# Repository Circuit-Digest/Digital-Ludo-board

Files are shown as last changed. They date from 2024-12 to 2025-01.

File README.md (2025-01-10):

# [Digital-Ludo-board](https://circuitdigest.com/microcontroller-projects/build-a-smart-digital-game-board-using-multicolour-pcb)

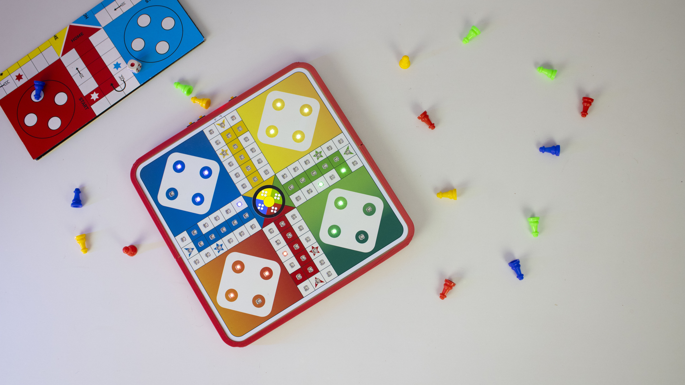
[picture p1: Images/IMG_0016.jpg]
Main Image


## Gallery

<table align="center">
  <tr>
    <td align="center">
      <a href="https://github.com/jobitjoseph/Digital-Ludo-board/blob/b7a14a51adeb144ec9624a0bab658bc6e6cb5062/Images/IMG_0016.jpg" target="_blank">
        
      </a>
    </td>
    <td align="center">
      <a href="https://github.com/jobitjoseph/Digital-Ludo-board/blob/fb9c06605a7f2c914b765a0e7e6bfde6a9d47ad6/Images/IMG_0014.jpg" target="_blank">
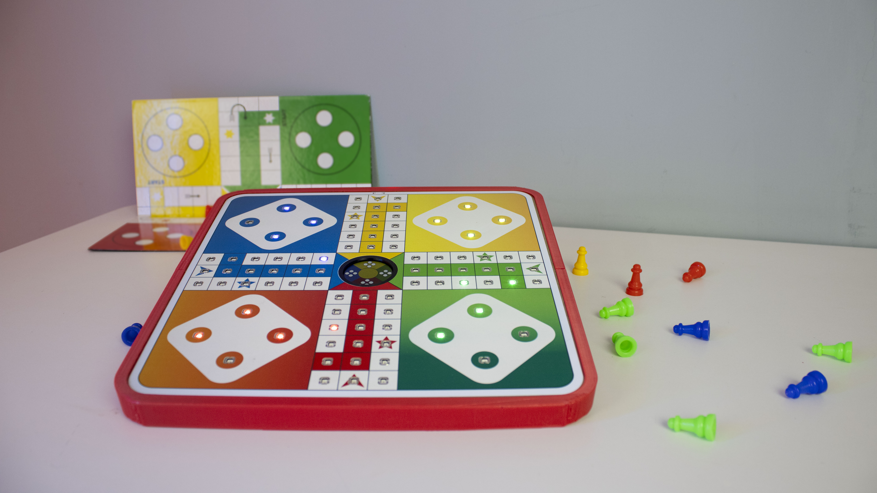
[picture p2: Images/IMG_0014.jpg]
        
      </a>
    </td>
  </tr>
  <tr>
    <td align="center">
      <a href="https://github.com/jobitjoseph/Digital-Ludo-board/blob/ef0574b0e37cc6b18bce47278ad40f484cababb1/Images/LudoRender1.png" target="_blank">
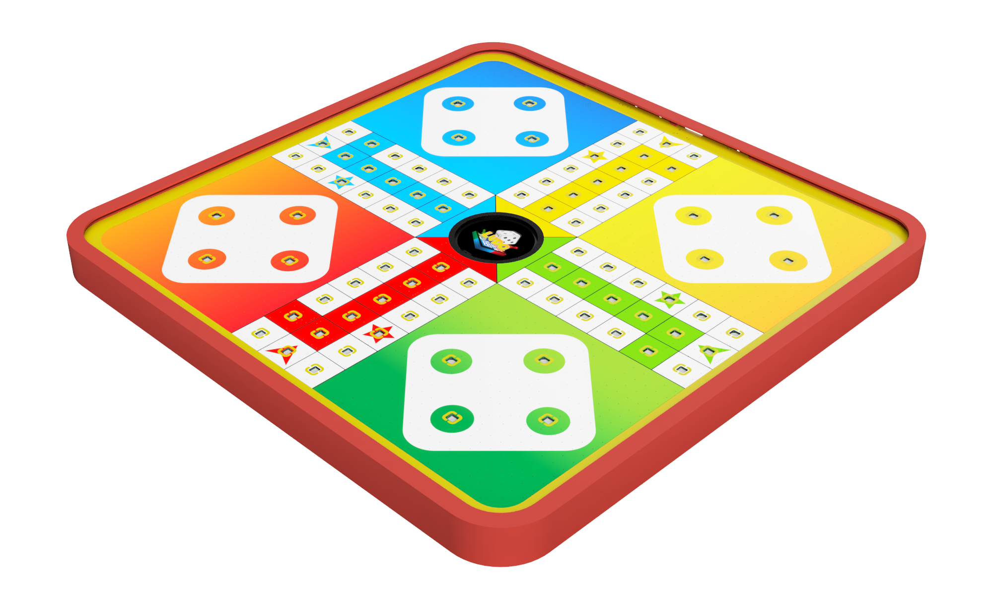
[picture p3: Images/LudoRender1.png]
        
      </a>
    </td>
    <td align="center">
      <a href="https://github.com/jobitjoseph/Digital-Ludo-board/blob/ef0574b0e37cc6b18bce47278ad40f484cababb1/Images/LudoRender2.png" target="_blank">
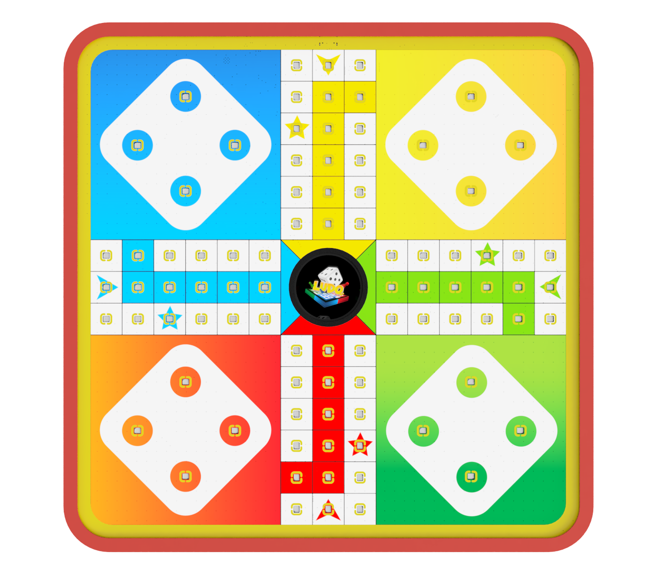
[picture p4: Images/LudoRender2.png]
        
      </a>
    </td>
  </tr>
</table>

---
Ludo, one of our cherished childhood board games, holds a special place in our hearts. Its simple yet engaging gameplay has provided countless hours of fun and bonding. However, as times have changed, so have our ways of enjoying these nostalgic pastimes. Today, children often experience classic games like Ludo through smartphones and gaming consoles, losing the physical gameplay and interpersonal connection of traditional board games.

What if we could bridge the gap between the old and the new by creating a digital version of the Ludo board? So let's create a Digital Ludo Board, a modern take on this classic game that combines the nostalgia of the physical game with the convenience and interactivity of the digital world. Designed and built from scratch, this is not only a fun project but also an opportunity to try out the new multicolor PCB.

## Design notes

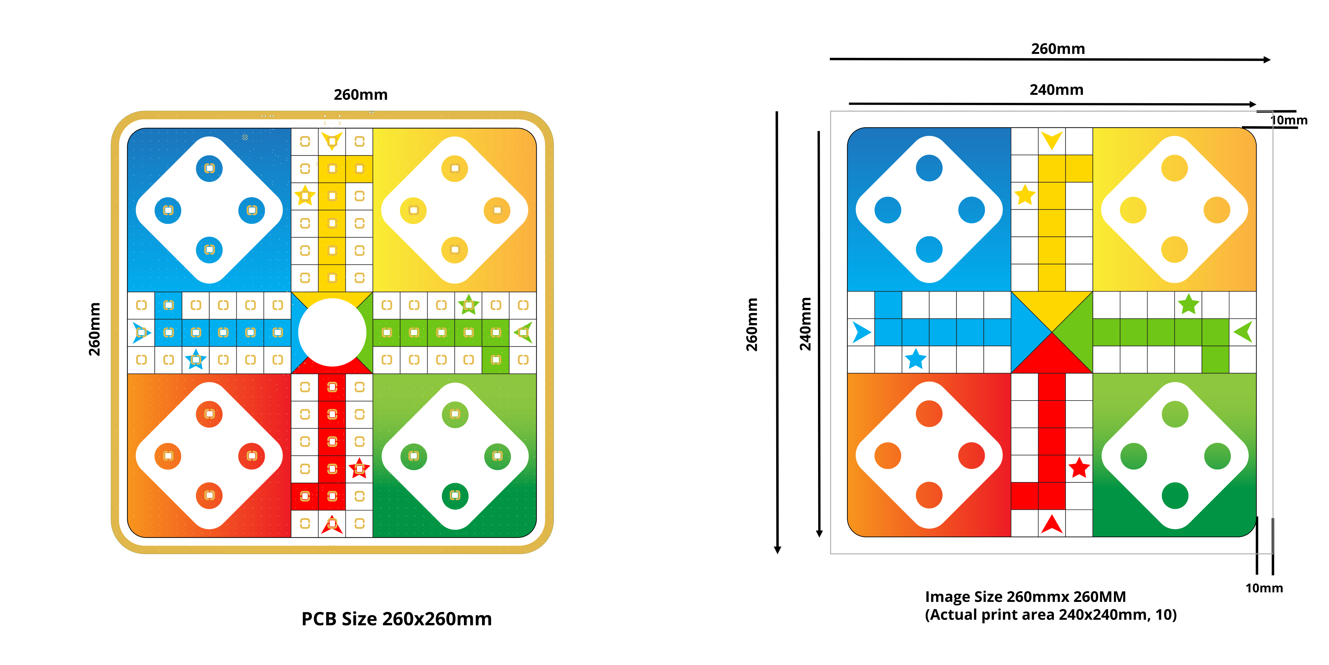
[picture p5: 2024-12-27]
Hardware/Reference image 1.png

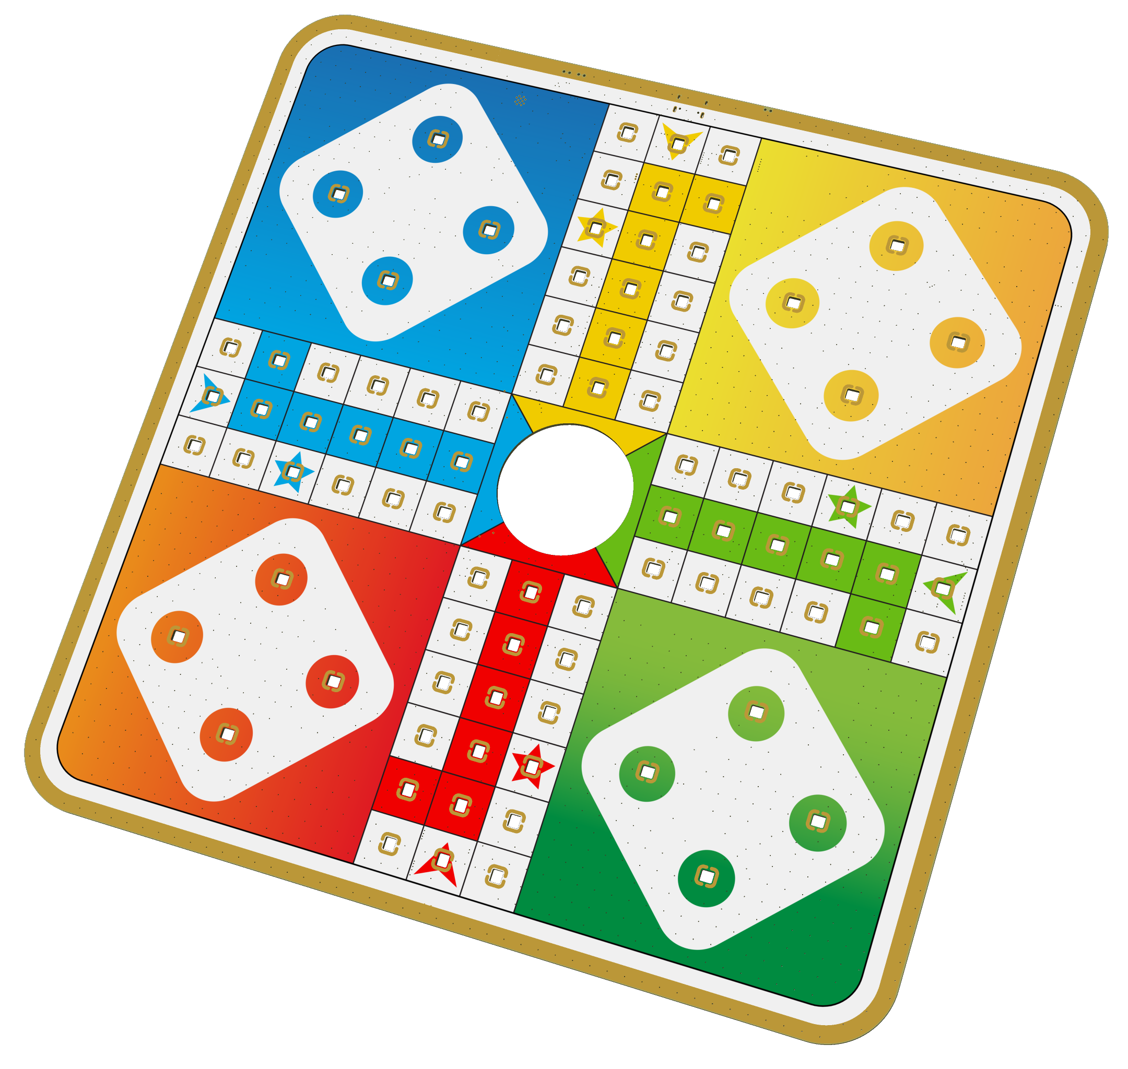
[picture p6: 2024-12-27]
Hardware/Reference image2.png

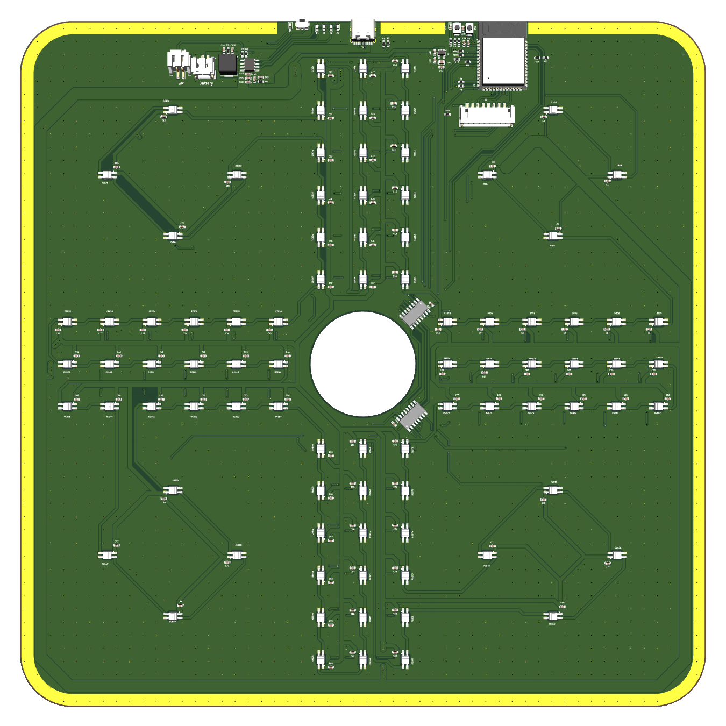
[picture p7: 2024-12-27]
Images/LudoBoard PCB 3D View Bottom.png

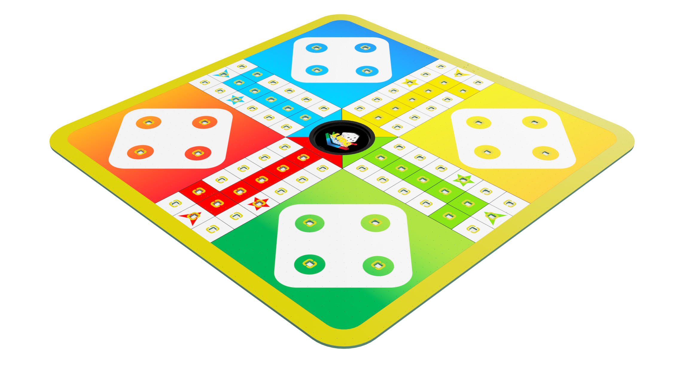
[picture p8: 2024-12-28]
Images/LUDO PCB 3D top.PNG

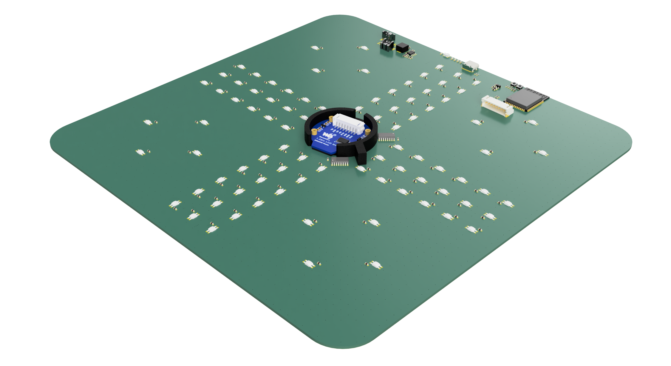
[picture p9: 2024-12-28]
Images/LUDO PCB 3D bottom.png

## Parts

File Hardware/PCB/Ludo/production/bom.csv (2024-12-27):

Designator | Footprint | Quantity | Value | LCSC Part #
C1, C10, C11, C12, C13, C14, C15, C16, C17, C18, C19, C2, C20, C21, C22, C23, C24, C25, C26, C27, C28, C29, C3, C30, C31, C32, C33, C34, C35, C36, C37, C38, C39, C4, C40, C41, C42, C43, C44, C45, C46, C47, C48, C49, C5, C50, C51, C52, C53, C54, C55, C56, C57, C58, C59, C6, C60, C61, C62, C63, C64, C65, C66, C67, C68, C69, C7, C70, C71, C72, C73, C74, C75, C76, C77, C78, C79, C8, C80, C81, C82, C83, C84, C85, C86, C87, C88, C9 | 0603 | 88 | 0.1uf
C100, C101, C103, C104 | 0603 | 4 | 22uf
C102 | 0603 | 1 | 22uf
C89, C92 | 0603 | 2 | 10u
C90 | 0603 | 1 | 470pF
C91 | 0805 | 1 | 2.2uF
C93, C96, C97, C98, C99 | 0603 | 5 | 10uf
C94 | 0603 | 1 | 1uf
C95 | 0603 | 1 | 0.1uf
D1 | 0603 | 1 | LED
D2, D3, D4, D5 | 0603 | 4 | LED
IC1, IC2 | 74HC595DQ100118 | 2 | 74HC595D
J1, J4 | JST_PH_S2B-PH-SM4-TB_1x02-1MP_P2.00mm_Horizontal | 2 | Conn_01x02_Male
J2 | USB_C_Receptacle_HRO_TYPE-C-31-M-12 | 1 | USB_C_Receptacle_USB2.0
J3 | JST_PH_S8B-PH-SM4-TB_1x08-1MP_P2.00mm_Horizontal | 1 | Conn_01x08
L1 | IND1uh | 1 | 1uH
LED2 | 0603 | 1 | POW_LED
R1, R2 | 0603 | 2 | 5.1K
R10 | 0603 | 1 | 20R
R11, R8 | 0603 | 2 | 2R
R12, R13, R14, R15, R16, R17, R18 | 0603 | 7 | 100k
R3, R4, R9 | 0603 | 3 | 10k
R5, R6 | 0603 | 2 | 27R
R7 | 0603 | 1 | 470R
RGB1, RGB10, RGB11, RGB12, RGB13, RGB14, RGB15, RGB16, RGB17, RGB18, RGB19, RGB2, RGB20, RGB21, RGB22, RGB23, RGB24, RGB25, RGB26, RGB27, RGB28, RGB29, RGB3, RGB30, RGB31, RGB32, RGB33, RGB34, RGB35, RGB36, RGB37, RGB38, RGB39, RGB4, RGB40, RGB41, RGB42, RGB43, RGB44, RGB45, RGB46, RGB47, RGB48, RGB49, RGB5, RGB50, RGB51, RGB52, RGB53, RGB54, RGB55, RGB56, RGB57, RGB58, RGB59, RGB6, RGB60, RGB61, RGB62, RGB63, RGB64, RGB65, RGB66, RGB67, RGB68, RGB69, RGB7, RGB70, RGB71, RGB72, RGB73, RGB74, RGB75, RGB76, RGB77, RGB78, RGB79, RGB8, RGB80, RGB81, RGB82, RGB83, RGB84, RGB85, RGB86, RGB87, RGB88, RGB9 | SK6812MINI-E_1 | 88 | SK6812MINI-E_C5149201
SW1 | Tactile 3x4x2mm TS-A010 | 1 | Boot
SW2 | Tactile 3x4x2mm TS-A010 | 1 | RST
SW3 | SW-SMD_TS24CA | 1 | Boot
U1 | IP5306-SOP8 | 1 | IP5306
U3 | ESP32-S3-WROOM-1 | 1 | ESP32-S3-WROOM-1
U6 | SOT-23-5 | 1 | MIC5219-3.3YM5

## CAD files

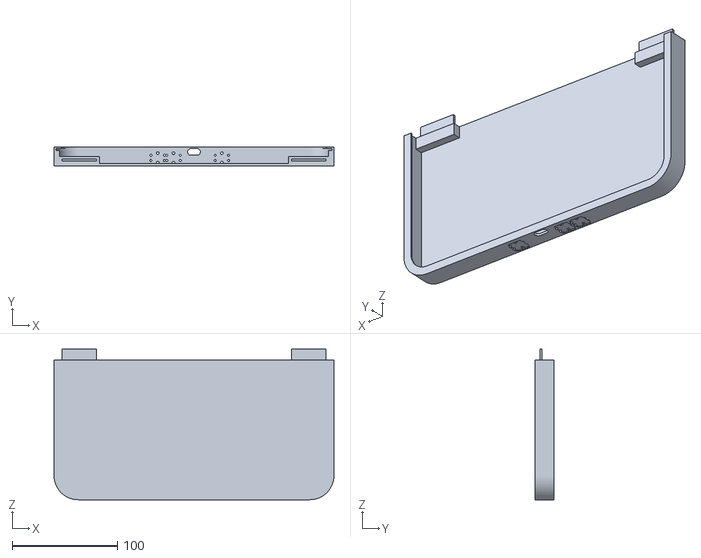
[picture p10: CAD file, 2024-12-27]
Hardware/3D parts/EnclosurePart2.stl
266.0 x 17.6 x 143.0

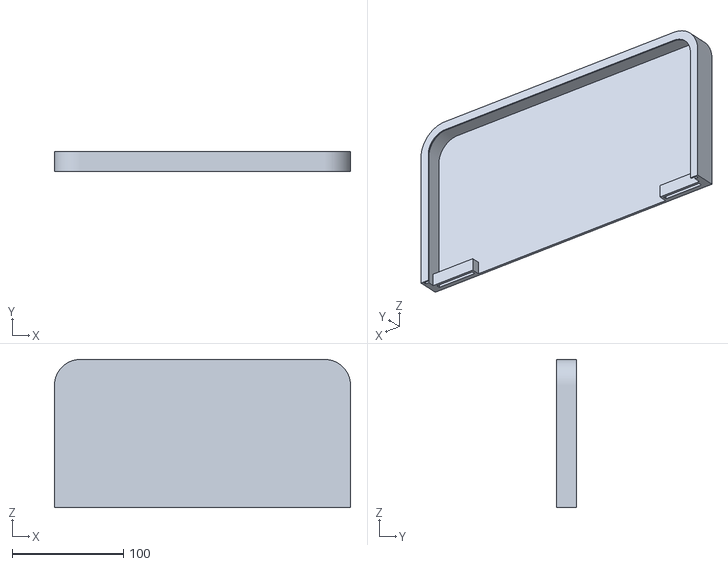
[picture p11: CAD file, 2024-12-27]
Hardware/3D parts/EnclosurePart1.stl
266.0 x 17.6 x 133.0

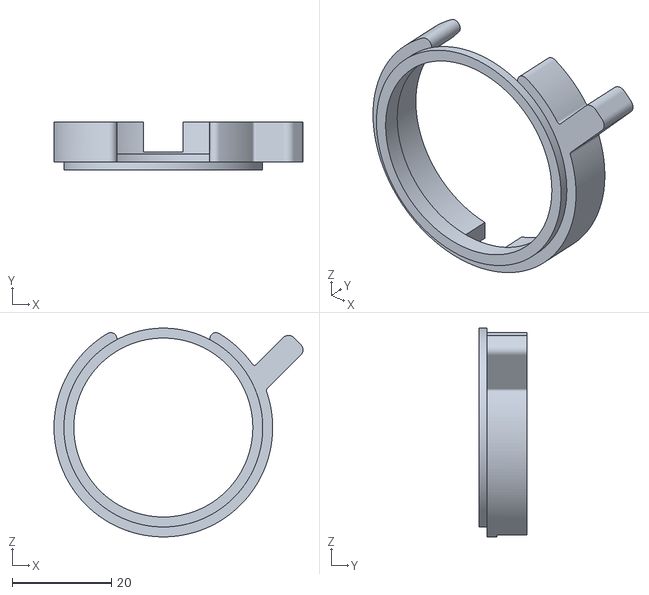
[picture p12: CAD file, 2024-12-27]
Hardware/3D parts/LCDMount.stl
50.1 x 9.60 x 42.0

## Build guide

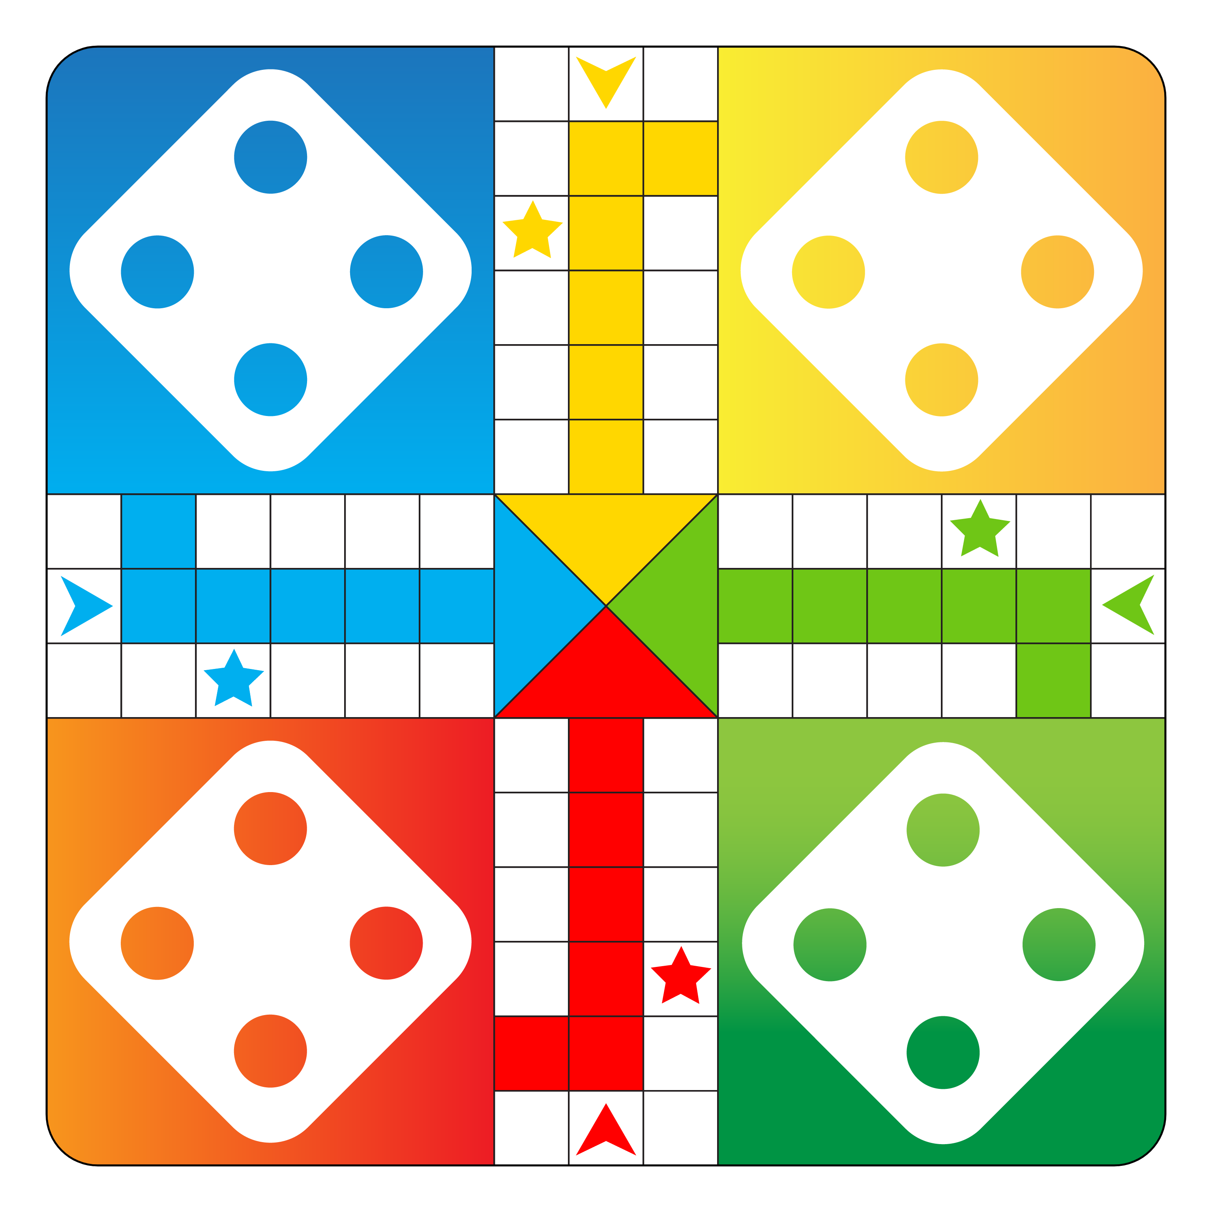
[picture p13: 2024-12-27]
Hardware/Top UV Printing Image .png

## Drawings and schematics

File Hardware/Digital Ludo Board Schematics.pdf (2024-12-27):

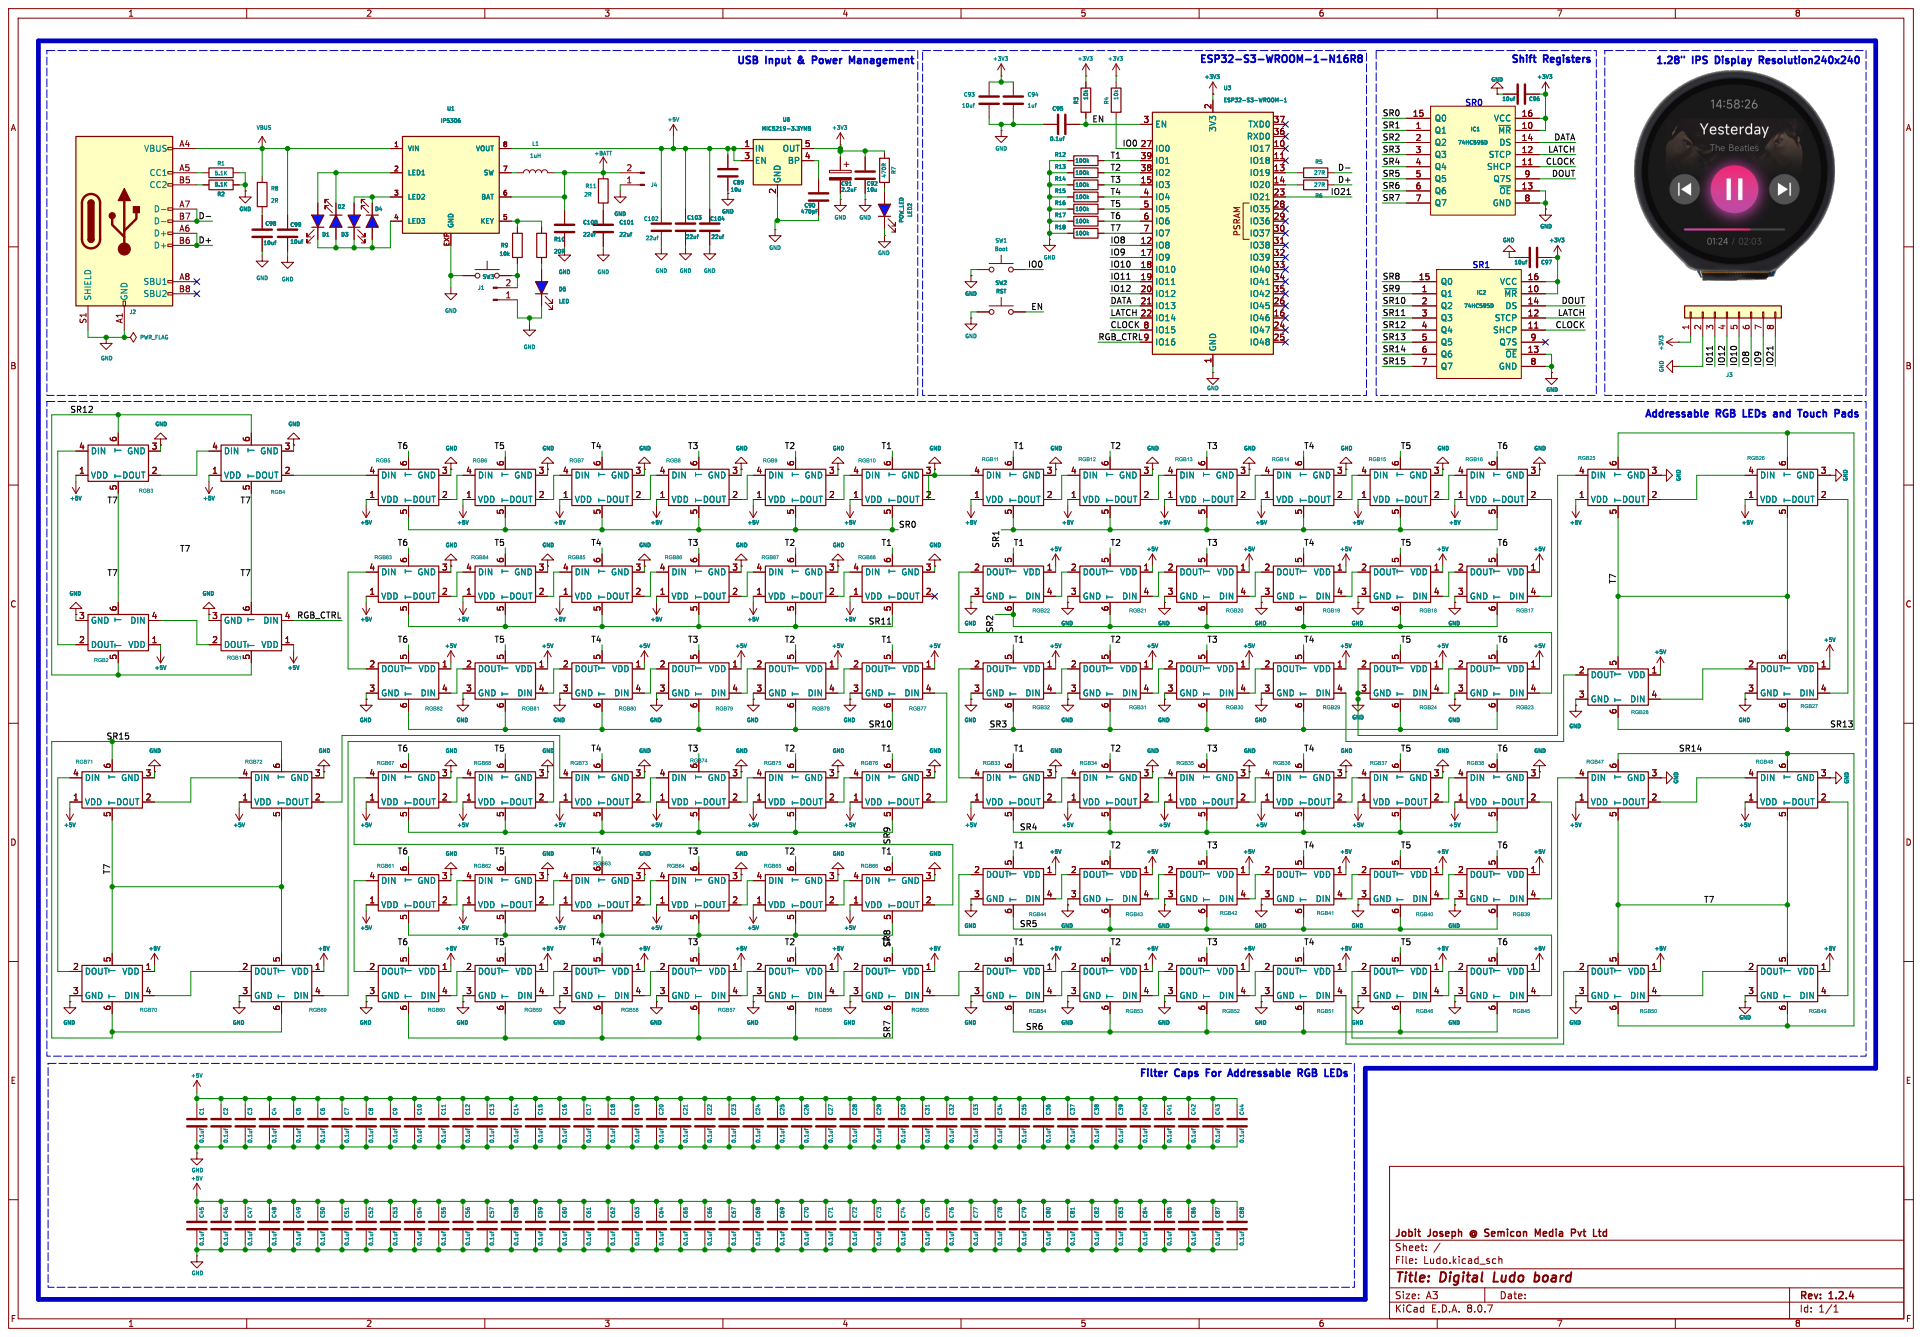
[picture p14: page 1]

Filter Caps For Addressable RGB LEDs

Id: 1/1 Title: Digital Ludo board

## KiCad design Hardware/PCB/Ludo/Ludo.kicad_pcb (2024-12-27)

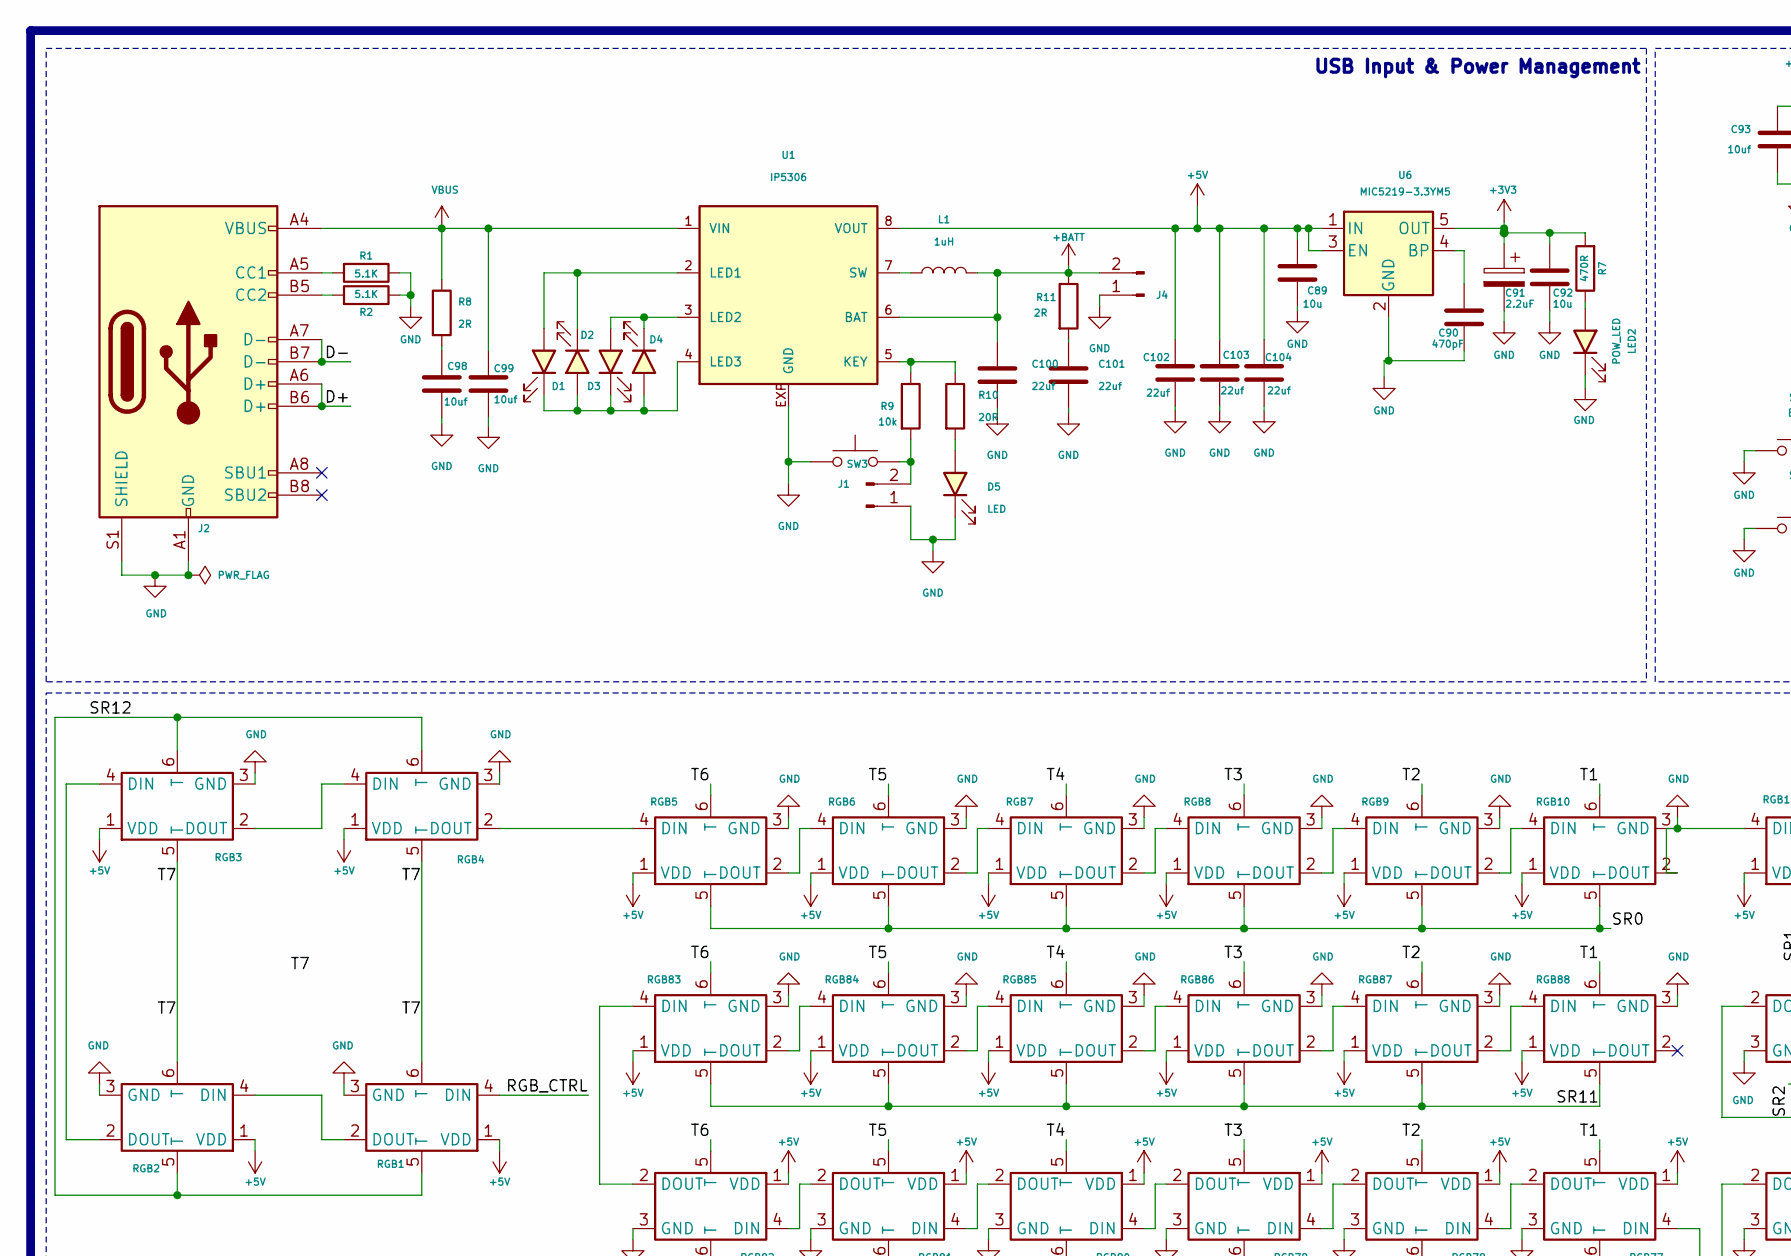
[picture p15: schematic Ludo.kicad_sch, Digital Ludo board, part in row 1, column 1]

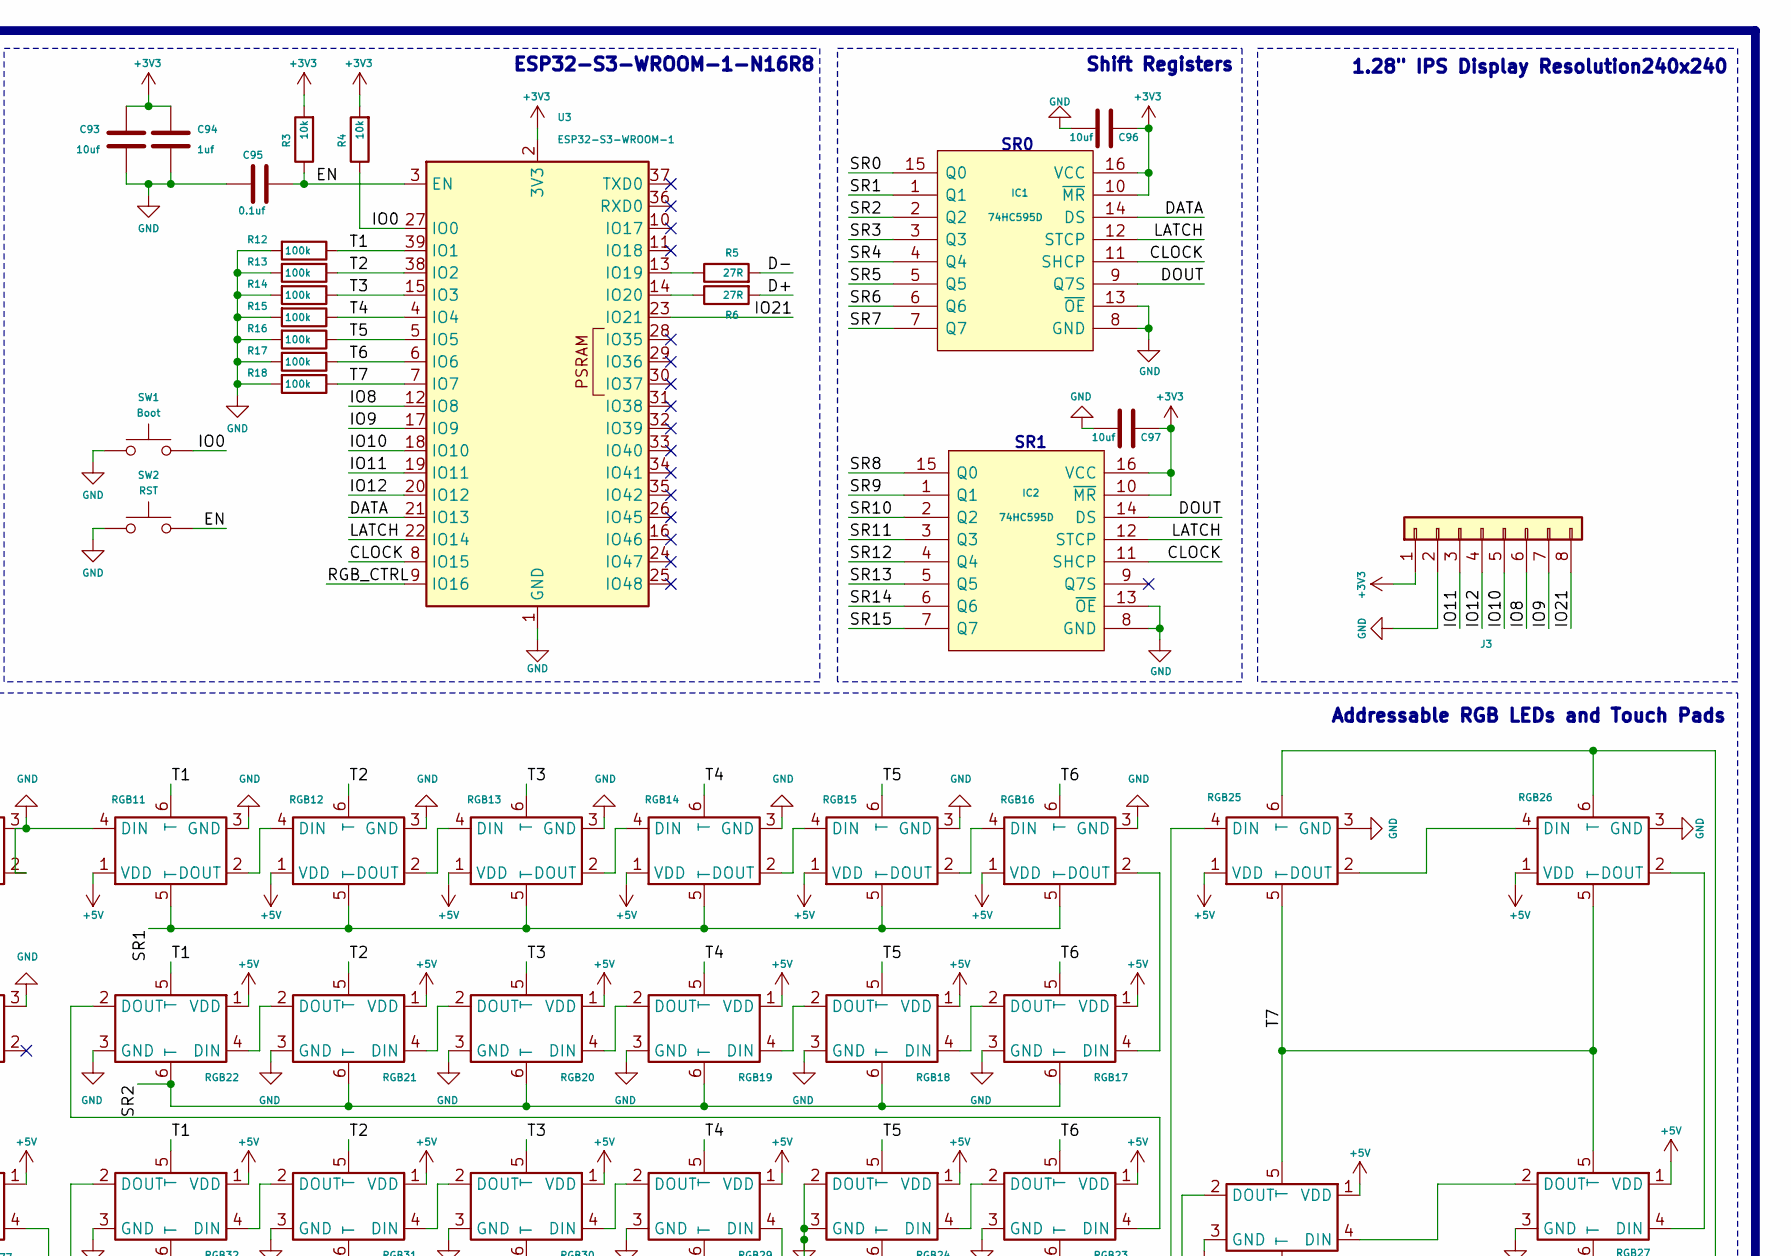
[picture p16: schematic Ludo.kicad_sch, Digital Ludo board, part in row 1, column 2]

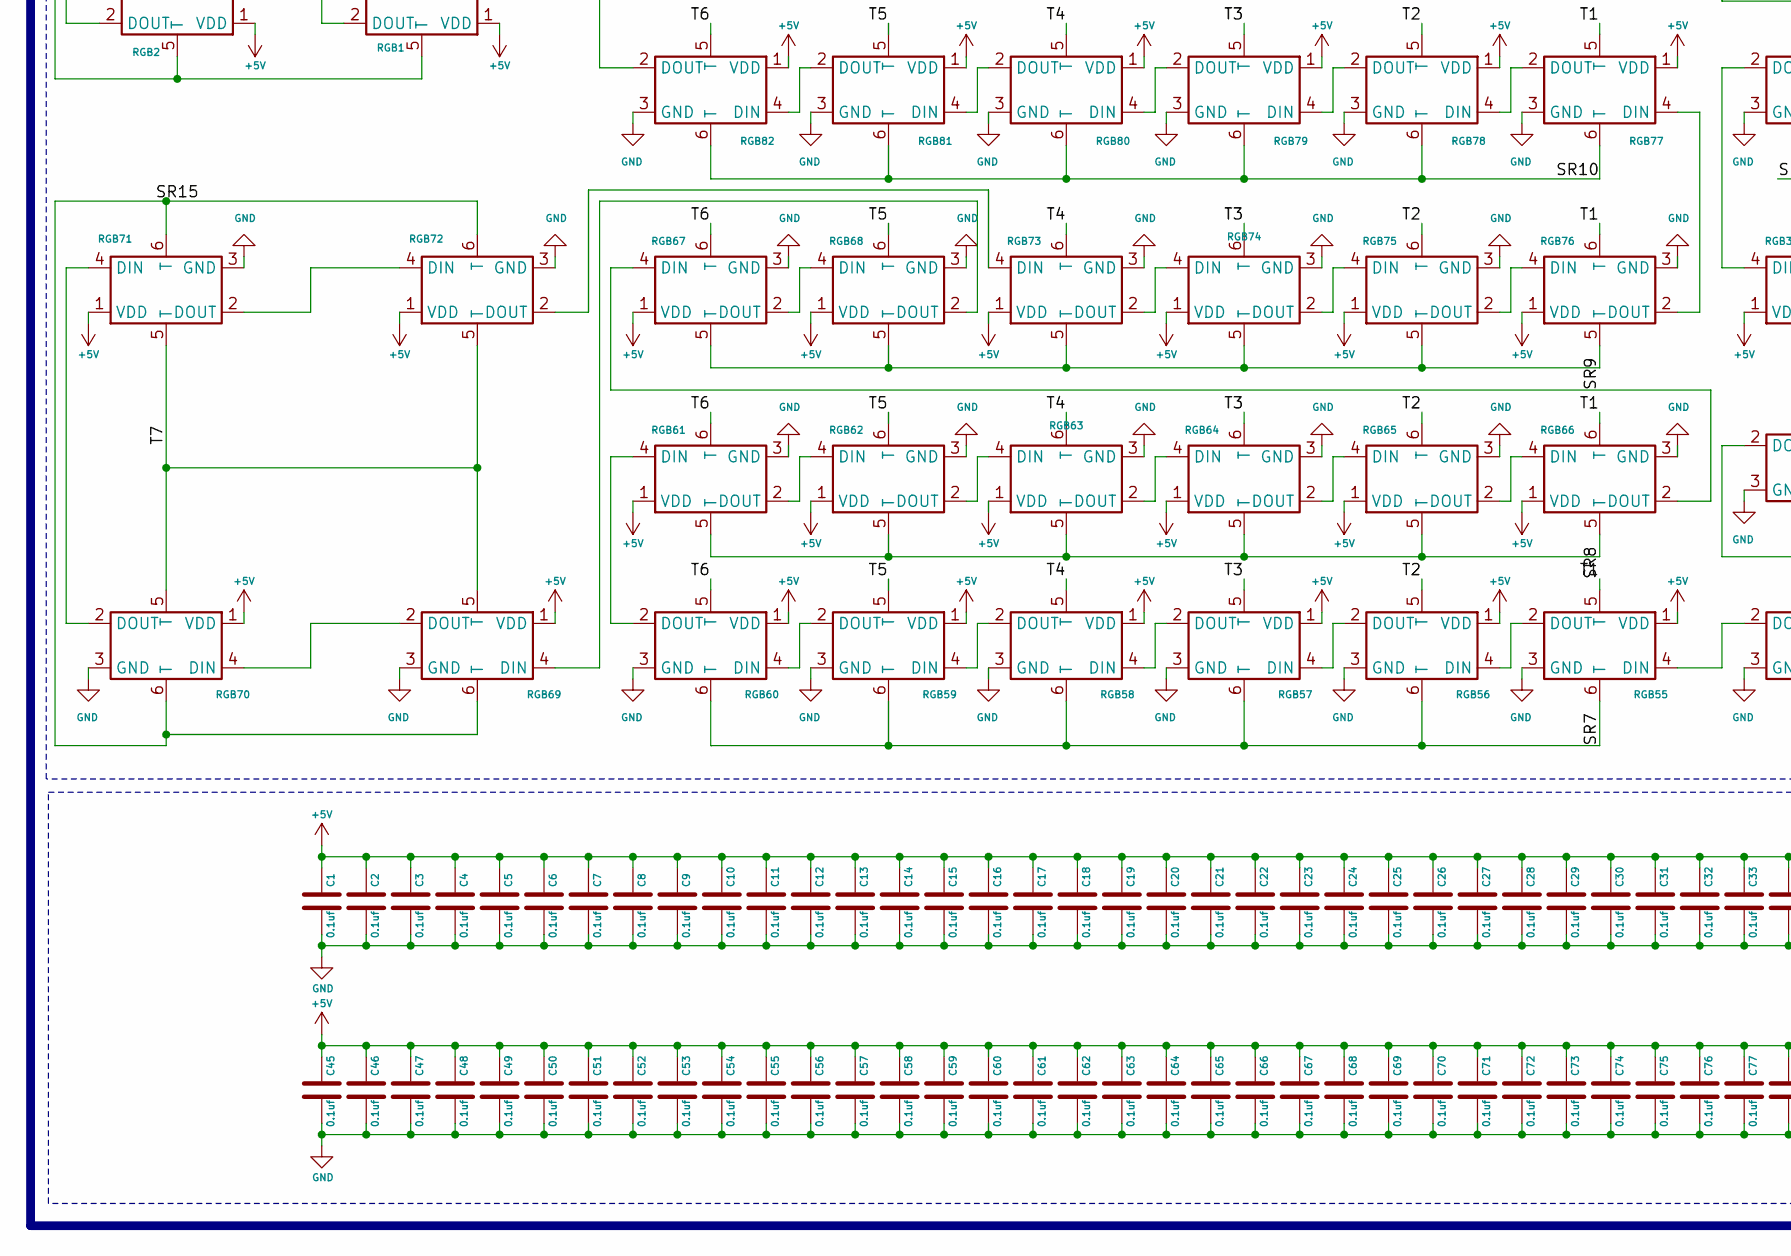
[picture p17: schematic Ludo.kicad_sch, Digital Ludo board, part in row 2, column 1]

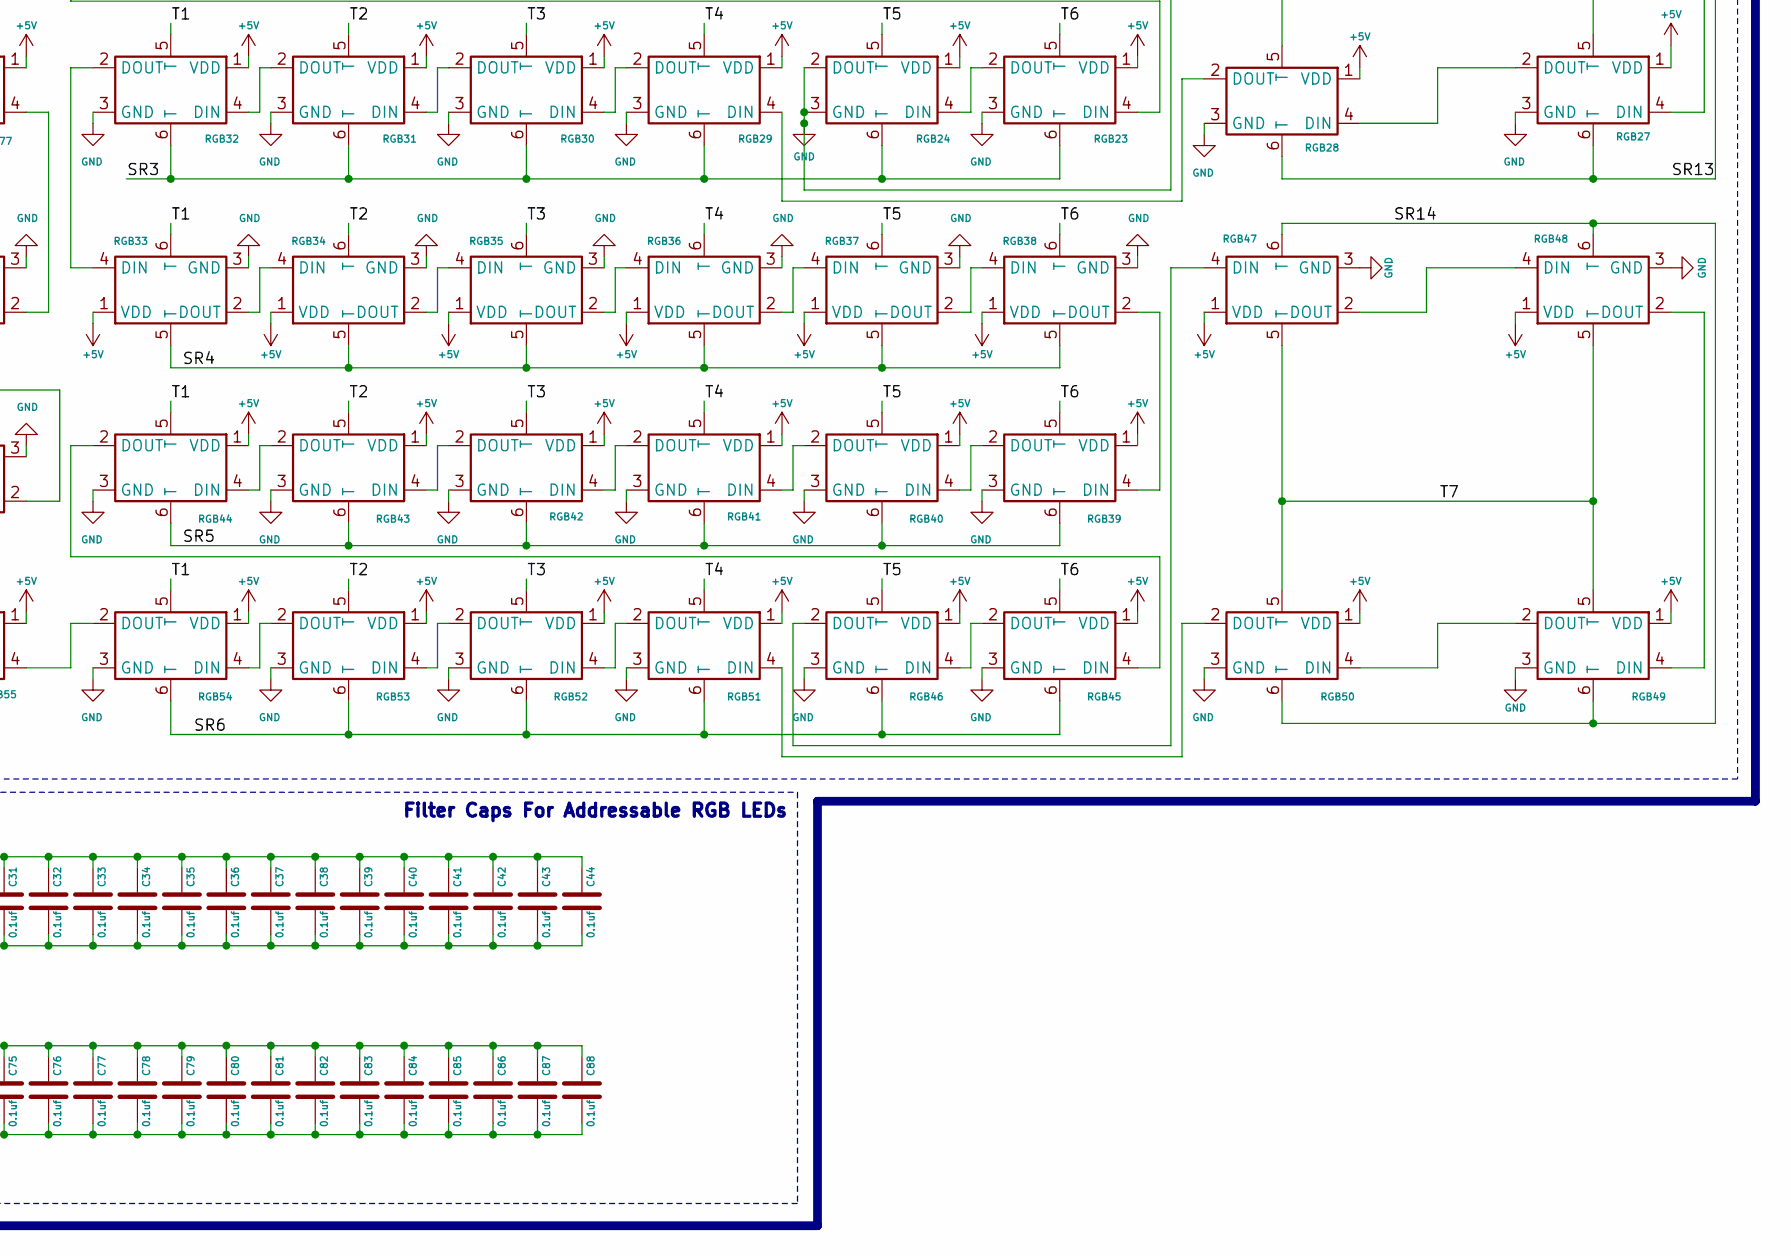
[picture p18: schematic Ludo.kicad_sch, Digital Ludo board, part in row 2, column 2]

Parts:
C1, C2, C3, C4, C5, C6, C7, C8, C9, C10, C11, C12, C13, C14, C15, C16, C17, C18, C19, C20, C21, C22, C23, C24, C25, C26, C27, C28, C29, C30, C31, C32, C33, C34, C35, C36, C37, C38, C39, C40, C41, C42, C43, C44, C45, C46, C47, C48, C49, C50, C51, C52, C53, C54, C55, C56, C57, C58, C59, C60, C61, C62, C63, C64, C65, C66, C67, C68, C69, C70, C71, C72, C73, C74, C75, C76, C77, C78, C79, C80, C81, C82, C83, C84, C85, C86, C87, C88, C95: 0.1uf; C_0603_1608Metric
C89, C92: 10u; C_0603_1608Metric
C90: 470pF; C_0603_1608Metric
C91: 2.2uF; C_0805_2012Metric
C93, C96, C97, C98, C99: 10uf; C_0603_1608Metric
C94: 1uf; C_0603_1608Metric
C100, C101, C102, C103, C104: 22uf; C_0603_1608Metric
D1, D2, D3, D4, D5: LED; LED_0603_1608Metric
IC1, IC2: 74HC595D; 74HC595DQ100118; Mouser Part Number 771-74HC595D-Q100
J1, J4: Conn_01x02_Male; JST_PH_S2B-PH-SM4-TB_1x02-1MP_P2.00mm_Horizontal
J2: USB_C_Receptacle_USB2.0; USB_C_Receptacle_HRO_TYPE-C-31-M-12
J3: Conn_01x08; JST_PH_S8B-PH-SM4-TB_1x08-1MP_P2.00mm_Horizontal
L1: 1uH; IND1uh
LED2: POW_LED; LED_0603_1608Metric
R1, R2: 5.1K; R_0603_1608Metric
R3, R4, R9: 10k; R_0603_1608Metric
R5, R6: 27R; R_0603_1608Metric
R7: 470R; R_0603_1608Metric
R8, R11: 2R; R_0603_1608Metric
R10: 20R; R_0603_1608Metric
R12, R13, R14, R15, R16, R17, R18: 100k; R_0603_1608Metric
RGB1, RGB2, RGB3, RGB4, RGB5, RGB6, RGB7, RGB8, RGB9, RGB10, RGB11, RGB12, RGB13, RGB14, RGB15, RGB16, RGB17, RGB18, RGB19, RGB20, RGB21, RGB22, RGB23, RGB24, RGB25, RGB26, RGB27, RGB28, RGB29, RGB30, RGB31, RGB32, RGB33, RGB34, RGB35, RGB36, RGB37, RGB38, RGB39, RGB40, RGB41, RGB42, RGB43, RGB44, RGB45, RGB46, RGB47, RGB48, RGB49, RGB50, RGB51, RGB52, RGB53, RGB54, RGB55, RGB56, RGB57, RGB58, RGB59, RGB60, RGB61, RGB62, RGB63, RGB64, RGB65, RGB66, RGB67, RGB68, RGB69, RGB70, RGB71, RGB72, RGB73, RGB74, RGB75, RGB76, RGB77, RGB78, RGB79, RGB80, RGB81, RGB82, RGB83, RGB84, RGB85, RGB86, RGB87, RGB88: SK6812MINI-E_C5149201; SK6812MINI-E_1
SW1: Boot; Tactile 3x4x2mm TS-A010
SW2: RST; Tactile 3x4x2mm TS-A010
SW3: Boot; SW-SMD_TS24CA
U1: IP5306; IP5306-SOP8
U3: ESP32-S3-WROOM-1
U6: MIC5219-3.3YM5; SOT-23-5

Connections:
+3V3: C91.1, C92.1, C93.1, C94.1, C96.1, C97.1, IC1.10 (~MR), IC1.16 (VCC), IC2.10 (~MR), IC2.16 (VCC), J3.1, R3.2, R4.2, R7.2, U3.2 (3V3), U6.5 (OUT)
+5V: C1.1, C2.1, C3.1, C4.1, C5.1, C6.1, C7.1, C8.1, C9.1, C10.1, C11.1, C12.1, C13.1, C14.1, C15.1, C16.1, C17.1, C18.1, C19.1, C20.1, C21.1, C22.1, C23.1, C24.1, C25.1, C26.1, C27.1, C28.1, C29.1, C30.1, C31.1, C32.1, C33.1, C34.1, C35.1, C36.1, C37.1, C38.1, C39.1, C40.1, C41.1, C42.1, C43.1, C44.1, C45.1, C46.1, C47.1, C48.1, C49.1, C50.1, C51.1, C52.1, C53.1, C54.1, C55.1, C56.1, C57.1, C58.1, C59.1, C60.1, C61.1, C62.1, C63.1, C64.1, C65.1, C66.1, C67.1, C68.1, C69.1, C70.1, C71.1, C72.1, C73.1, C74.1, C75.1, C76.1, C77.1, C78.1, C79.1, C80.1, C81.1, C82.1, C83.1, C84.1, C85.1, C86.1, C87.1, C88.1, C89.1, C102.1, C103.1, C104.1, RGB1.1 (VDD), RGB2.1 (VDD), RGB3.1 (VDD), RGB4.1 (VDD), RGB5.1 (VDD), RGB6.1 (VDD), RGB7.1 (VDD), RGB8.1 (VDD), RGB9.1 (VDD), RGB10.1 (VDD), RGB11.1 (VDD), RGB12.1 (VDD), RGB13.1 (VDD), RGB14.1 (VDD), RGB15.1 (VDD), RGB16.1 (VDD), RGB17.1 (VDD), RGB18.1 (VDD), RGB19.1 (VDD), RGB20.1 (VDD), RGB21.1 (VDD), RGB22.1 (VDD), RGB23.1 (VDD), RGB24.1 (VDD), RGB25.1 (VDD), RGB26.1 (VDD), RGB27.1 (VDD), RGB28.1 (VDD), RGB29.1 (VDD), RGB30.1 (VDD), RGB31.1 (VDD), RGB32.1 (VDD), RGB33.1 (VDD), RGB34.1 (VDD), RGB35.1 (VDD), RGB36.1 (VDD), RGB37.1 (VDD), RGB38.1 (VDD), RGB39.1 (VDD), RGB40.1 (VDD), RGB41.1 (VDD), RGB42.1 (VDD), RGB43.1 (VDD), RGB44.1 (VDD), RGB45.1 (VDD), RGB46.1 (VDD), RGB47.1 (VDD), RGB48.1 (VDD), RGB49.1 (VDD), RGB50.1 (VDD), RGB51.1 (VDD), RGB52.1 (VDD), RGB53.1 (VDD), RGB54.1 (VDD), RGB55.1 (VDD), RGB56.1 (VDD), RGB57.1 (VDD), RGB58.1 (VDD), RGB59.1 (VDD), RGB60.1 (VDD), RGB61.1 (VDD), RGB62.1 (VDD), RGB63.1 (VDD), RGB64.1 (VDD), RGB65.1 (VDD), RGB66.1 (VDD), RGB67.1 (VDD), RGB68.1 (VDD), RGB69.1 (VDD), RGB70.1 (VDD), RGB71.1 (VDD), RGB72.1 (VDD), RGB73.1 (VDD), RGB74.1 (VDD), RGB75.1 (VDD), RGB76.1 (VDD), RGB77.1 (VDD), RGB78.1 (VDD), RGB79.1 (VDD), RGB80.1 (VDD), RGB81.1 (VDD), RGB82.1 (VDD), RGB83.1 (VDD), RGB84.1 (VDD), RGB85.1 (VDD), RGB86.1 (VDD), RGB87.1 (VDD), RGB88.1 (VDD), U1.8 (VOUT), U6.1 (IN), U6.3 (EN)
+BATT: C100.1, J4.2, L1.2, R11.1, U1.6 (BAT)
/CLOCK: IC1.11 (SHCP), IC2.11 (SHCP), U3.8 (IO15)
/D+: J2.A6 (D+), J2.B6 (D+), R6.2
/D-: J2.A7 (D-), J2.B7 (D-), R5.2
/DATA: IC1.14 (DS), U3.21 (IO13)
/DOUT: IC1.9 (Q7S), IC2.14 (DS)
/EN: C95.1, R3.1, SW2.2, U3.3 (EN)
/IO0: R4.1, SW1.2, U3.27 (IO0)
/IO8: J3.6, U3.12 (IO8)
/IO9: J3.7, U3.17 (IO9)
/IO10: J3.5, U3.18 (IO10)
/IO11: J3.3, U3.19 (IO11)
/IO12: J3.4, U3.20 (IO12)
/IO21: J3.8, U3.23 (IO21)
/LATCH: IC1.12 (STCP), IC2.12 (STCP), U3.22 (IO14)
/RGB_CTRL: RGB1.4 (DIN), U3.9 (IO16)
/SR0: IC1.15 (Q0), RGB5.5 (T), RGB6.5 (T), RGB7.5 (T), RGB8.5 (T), RGB9.5 (T), RGB10.5 (T)
/SR1: IC1.1 (Q1), RGB11.5 (T), RGB12.5 (T), RGB13.5 (T), RGB14.5 (T), RGB15.5 (T), RGB16.5 (T)
/SR2: IC1.2 (Q2), RGB17.6 (T), RGB18.6 (T), RGB19.6 (T), RGB20.6 (T), RGB21.6 (T), RGB22.6 (T)
/SR3: IC1.3 (Q3), RGB23.6 (T), RGB24.6 (T), RGB29.6 (T), RGB30.6 (T), RGB31.6 (T), RGB32.6 (T)
/SR4: IC1.4 (Q4), RGB33.5 (T), RGB34.5 (T), RGB35.5 (T), RGB36.5 (T), RGB37.5 (T), RGB38.5 (T)
/SR5: IC1.5 (Q5), RGB39.6 (T), RGB40.6 (T), RGB41.6 (T), RGB42.6 (T), RGB43.6 (T), RGB44.6 (T)
/SR6: IC1.6 (Q6), RGB45.6 (T), RGB46.6 (T), RGB51.6 (T), RGB52.6 (T), RGB53.6 (T), RGB54.6 (T)
/SR7: IC1.7 (Q7), RGB55.6 (T), RGB56.6 (T), RGB57.6 (T), RGB58.6 (T), RGB59.6 (T), RGB60.6 (T)
/SR8: IC2.15 (Q0), RGB61.5 (T), RGB62.5 (T), RGB63.5 (T), RGB64.5 (T), RGB65.5 (T), RGB66.5 (T)
/SR9: IC2.1 (Q1), RGB67.5 (T), RGB68.5 (T), RGB73.5 (T), RGB74.5 (T), RGB75.5 (T), RGB76.5 (T)
/SR10: IC2.2 (Q2), RGB77.6 (T), RGB78.6 (T), RGB79.6 (T), RGB80.6 (T), RGB81.6 (T), RGB82.6 (T)
/SR11: IC2.3 (Q3), RGB83.5 (T), RGB84.5 (T), RGB85.5 (T), RGB86.5 (T), RGB87.5 (T), RGB88.5 (T)
/SR12: IC2.4 (Q4), RGB1.5 (T), RGB2.5 (T), RGB3.6 (T), RGB4.6 (T)
/SR13: IC2.5 (Q5), RGB25.6 (T), RGB26.6 (T), RGB27.6 (T), RGB28.6 (T)
/SR14: IC2.6 (Q6), RGB47.6 (T), RGB48.6 (T), RGB49.6 (T), RGB50.6 (T)
/SR15: IC2.7 (Q7), RGB69.6 (T), RGB70.6 (T), RGB71.6 (T), RGB72.6 (T)
/T1: R12.1, RGB10.6 (T), RGB11.6 (T), RGB22.5 (T), RGB32.5 (T), RGB33.6 (T), RGB44.5 (T), RGB54.5 (T), RGB55.5 (T), RGB66.6 (T), RGB76.6 (T), RGB77.5 (T), RGB88.6 (T), U3.39 (IO1)
/T2: R13.1, RGB9.6 (T), RGB12.6 (T), RGB21.5 (T), RGB31.5 (T), RGB34.6 (T), RGB43.5 (T), RGB53.5 (T), RGB56.5 (T), RGB65.6 (T), RGB75.6 (T), RGB78.5 (T), RGB87.6 (T), U3.38 (IO2)
/T3: R14.1, RGB8.6 (T), RGB13.6 (T), RGB20.5 (T), RGB30.5 (T), RGB35.6 (T), RGB42.5 (T), RGB52.5 (T), RGB57.5 (T), RGB64.6 (T), RGB74.6 (T), RGB79.5 (T), RGB86.6 (T), U3.15 (IO3)
/T4: R15.1, RGB7.6 (T), RGB14.6 (T), RGB19.5 (T), RGB29.5 (T), RGB36.6 (T), RGB41.5 (T), RGB51.5 (T), RGB58.5 (T), RGB63.6 (T), RGB73.6 (T), RGB80.5 (T), RGB85.6 (T), U3.4 (IO4)
/T5: R16.1, RGB6.6 (T), RGB15.6 (T), RGB18.5 (T), RGB24.5 (T), RGB37.6 (T), RGB40.5 (T), RGB46.5 (T), RGB59.5 (T), RGB62.6 (T), RGB68.6 (T), RGB81.5 (T), RGB84.6 (T), U3.5 (IO5)
/T6: R17.1, RGB5.6 (T), RGB16.6 (T), RGB17.5 (T), RGB23.5 (T), RGB38.6 (T), RGB39.5 (T), RGB45.5 (T), RGB60.5 (T), RGB61.6 (T), RGB67.6 (T), RGB82.5 (T), RGB83.6 (T), U3.6 (IO6)
/T7: R18.1, RGB1.6 (T), RGB2.6 (T), RGB3.5 (T), RGB4.5 (T), RGB25.5 (T), RGB26.5 (T), RGB27.5 (T), RGB28.5 (T), RGB47.5 (T), RGB48.5 (T), RGB49.5 (T), RGB50.5 (T), RGB69.5 (T), RGB70.5 (T), RGB71.5 (T), RGB72.5 (T), U3.7 (IO7)
unnamed: C98.1, R8.2
unnamed: C101.1, R11.2
unnamed: D1.2 (A), D2.1 (K), U1.2 (LED1)
unnamed: D1.1 (K), D2.2 (A), D3.1 (K), D4.2 (A), U1.4 (LED3)
unnamed: D3.2 (A), D4.1 (K), U1.3 (LED2)
unnamed: D5.2 (A), R10.2
unnamed: J1.2, R9.2, SW3.2
unnamed: J2.A5 (CC1), R1.2
unnamed: J2.B5 (CC2), R2.2
unnamed: LED2.2 (A), R7.1
unnamed: RGB1.2 (DOUT), RGB2.4 (DIN)
unnamed: RGB2.2 (DOUT), RGB3.4 (DIN)
unnamed: RGB3.2 (DOUT), RGB4.4 (DIN)
unnamed: RGB4.2 (DOUT), RGB5.4 (DIN)
unnamed: RGB5.2 (DOUT), RGB6.4 (DIN)
unnamed: RGB6.2 (DOUT), RGB7.4 (DIN)
unnamed: RGB7.2 (DOUT), RGB8.4 (DIN)
unnamed: RGB8.2 (DOUT), RGB9.4 (DIN)
unnamed: RGB9.2 (DOUT), RGB10.4 (DIN)
unnamed: RGB11.2 (DOUT), RGB12.4 (DIN)
unnamed: RGB12.2 (DOUT), RGB13.4 (DIN)
unnamed: RGB13.2 (DOUT), RGB14.4 (DIN)
unnamed: RGB14.2 (DOUT), RGB15.4 (DIN)
unnamed: RGB15.2 (DOUT), RGB16.4 (DIN)
unnamed: RGB16.2 (DOUT), RGB17.4 (DIN)
unnamed: RGB17.2 (DOUT), RGB18.4 (DIN)
unnamed: RGB18.2 (DOUT), RGB19.4 (DIN)
unnamed: RGB19.2 (DOUT), RGB20.4 (DIN)
unnamed: RGB20.2 (DOUT), RGB21.4 (DIN)
unnamed: RGB21.2 (DOUT), RGB22.4 (DIN)
unnamed: RGB22.2 (DOUT), RGB23.4 (DIN)
unnamed: RGB23.2 (DOUT), RGB24.4 (DIN)
unnamed: RGB25.2 (DOUT), RGB26.4 (DIN)
unnamed: RGB26.2 (DOUT), RGB27.4 (DIN)
unnamed: RGB27.2 (DOUT), RGB28.4 (DIN)
unnamed: RGB28.2 (DOUT), RGB29.4 (DIN)
unnamed: RGB29.2 (DOUT), RGB30.4 (DIN)
unnamed: RGB30.2 (DOUT), RGB31.4 (DIN)
unnamed: RGB31.2 (DOUT), RGB32.4 (DIN)
unnamed: RGB32.2 (DOUT), RGB33.4 (DIN)
unnamed: RGB33.2 (DOUT), RGB34.4 (DIN)
unnamed: RGB34.2 (DOUT), RGB35.4 (DIN)
unnamed: RGB35.2 (DOUT), RGB36.4 (DIN)
unnamed: RGB36.2 (DOUT), RGB37.4 (DIN)
unnamed: RGB37.2 (DOUT), RGB38.4 (DIN)
unnamed: RGB38.2 (DOUT), RGB39.4 (DIN)
unnamed: RGB39.2 (DOUT), RGB40.4 (DIN)
unnamed: RGB40.2 (DOUT), RGB41.4 (DIN)
unnamed: RGB41.2 (DOUT), RGB42.4 (DIN)
unnamed: RGB42.2 (DOUT), RGB43.4 (DIN)
unnamed: RGB43.2 (DOUT), RGB44.4 (DIN)
unnamed: RGB44.2 (DOUT), RGB45.4 (DIN)
unnamed: RGB45.2 (DOUT), RGB46.4 (DIN)
unnamed: RGB46.2 (DOUT), RGB47.4 (DIN)
unnamed: RGB47.2 (DOUT), RGB48.4 (DIN)
unnamed: RGB48.2 (DOUT), RGB49.4 (DIN)
unnamed: RGB49.2 (DOUT), RGB50.4 (DIN)
unnamed: RGB50.2 (DOUT), RGB51.4 (DIN)
unnamed: RGB51.2 (DOUT), RGB52.4 (DIN)
unnamed: RGB52.2 (DOUT), RGB53.4 (DIN)
unnamed: RGB53.2 (DOUT), RGB54.4 (DIN)
unnamed: RGB54.2 (DOUT), RGB55.4 (DIN)
unnamed: RGB55.2 (DOUT), RGB56.4 (DIN)
unnamed: RGB56.2 (DOUT), RGB57.4 (DIN)
unnamed: RGB57.2 (DOUT), RGB58.4 (DIN)
unnamed: RGB58.2 (DOUT), RGB59.4 (DIN)
unnamed: RGB59.2 (DOUT), RGB60.4 (DIN)
unnamed: RGB60.2 (DOUT), RGB61.4 (DIN)
unnamed: RGB61.2 (DOUT), RGB62.4 (DIN)
unnamed: RGB62.2 (DOUT), RGB63.4 (DIN)
unnamed: RGB63.2 (DOUT), RGB64.4 (DIN)
unnamed: RGB64.2 (DOUT), RGB65.4 (DIN)
unnamed: RGB65.2 (DOUT), RGB66.4 (DIN)
unnamed: RGB66.2 (DOUT), RGB67.4 (DIN)
unnamed: RGB67.2 (DOUT), RGB68.4 (DIN)
unnamed: RGB68.2 (DOUT), RGB69.4 (DIN)
unnamed: RGB69.2 (DOUT), RGB70.4 (DIN)
unnamed: RGB70.2 (DOUT), RGB71.4 (DIN)
unnamed: RGB71.2 (DOUT), RGB72.4 (DIN)
unnamed: RGB72.2 (DOUT), RGB73.4 (DIN)
unnamed: RGB73.2 (DOUT), RGB74.4 (DIN)
unnamed: RGB74.2 (DOUT), RGB75.4 (DIN)
unnamed: RGB75.2 (DOUT), RGB76.4 (DIN)
unnamed: RGB76.2 (DOUT), RGB77.4 (DIN)
unnamed: RGB77.2 (DOUT), RGB78.4 (DIN)
unnamed: RGB78.2 (DOUT), RGB79.4 (DIN)
unnamed: RGB79.2 (DOUT), RGB80.4 (DIN)
unnamed: RGB80.2 (DOUT), RGB81.4 (DIN)
unnamed: RGB81.2 (DOUT), RGB82.4 (DIN)
unnamed: RGB82.2 (DOUT), RGB83.4 (DIN)
unnamed: RGB83.2 (DOUT), RGB84.4 (DIN)
unnamed: RGB84.2 (DOUT), RGB85.4 (DIN)
unnamed: RGB85.2 (DOUT), RGB86.4 (DIN)
unnamed: RGB86.2 (DOUT), RGB87.4 (DIN)
unnamed: RGB87.2 (DOUT), RGB88.4 (DIN)
unnamed: R9.1, R10.1, U1.5 (KEY)
unnamed: L1.1, U1.7 (SW)
unnamed: R5.1, U3.13 (IO19)
unnamed: R6.1, U3.14 (IO20)
unnamed: C90.1, U6.4 (BP)
VBUS: C99.1, J2.A4 (VBUS), J2.A9 (VBUS), J2.B4 (VBUS), J2.B9 (VBUS), R8.1, U1.1 (VIN)

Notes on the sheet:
Shift Registers
SR0
Filter Caps For Addressable RGB LEDs
Addressable RGB LEDs and Touch Pads
ESP32-S3-WROOM-1-N16R8
USB Input & Power Management
SR1
1.28" IPS Display Resolution240x240

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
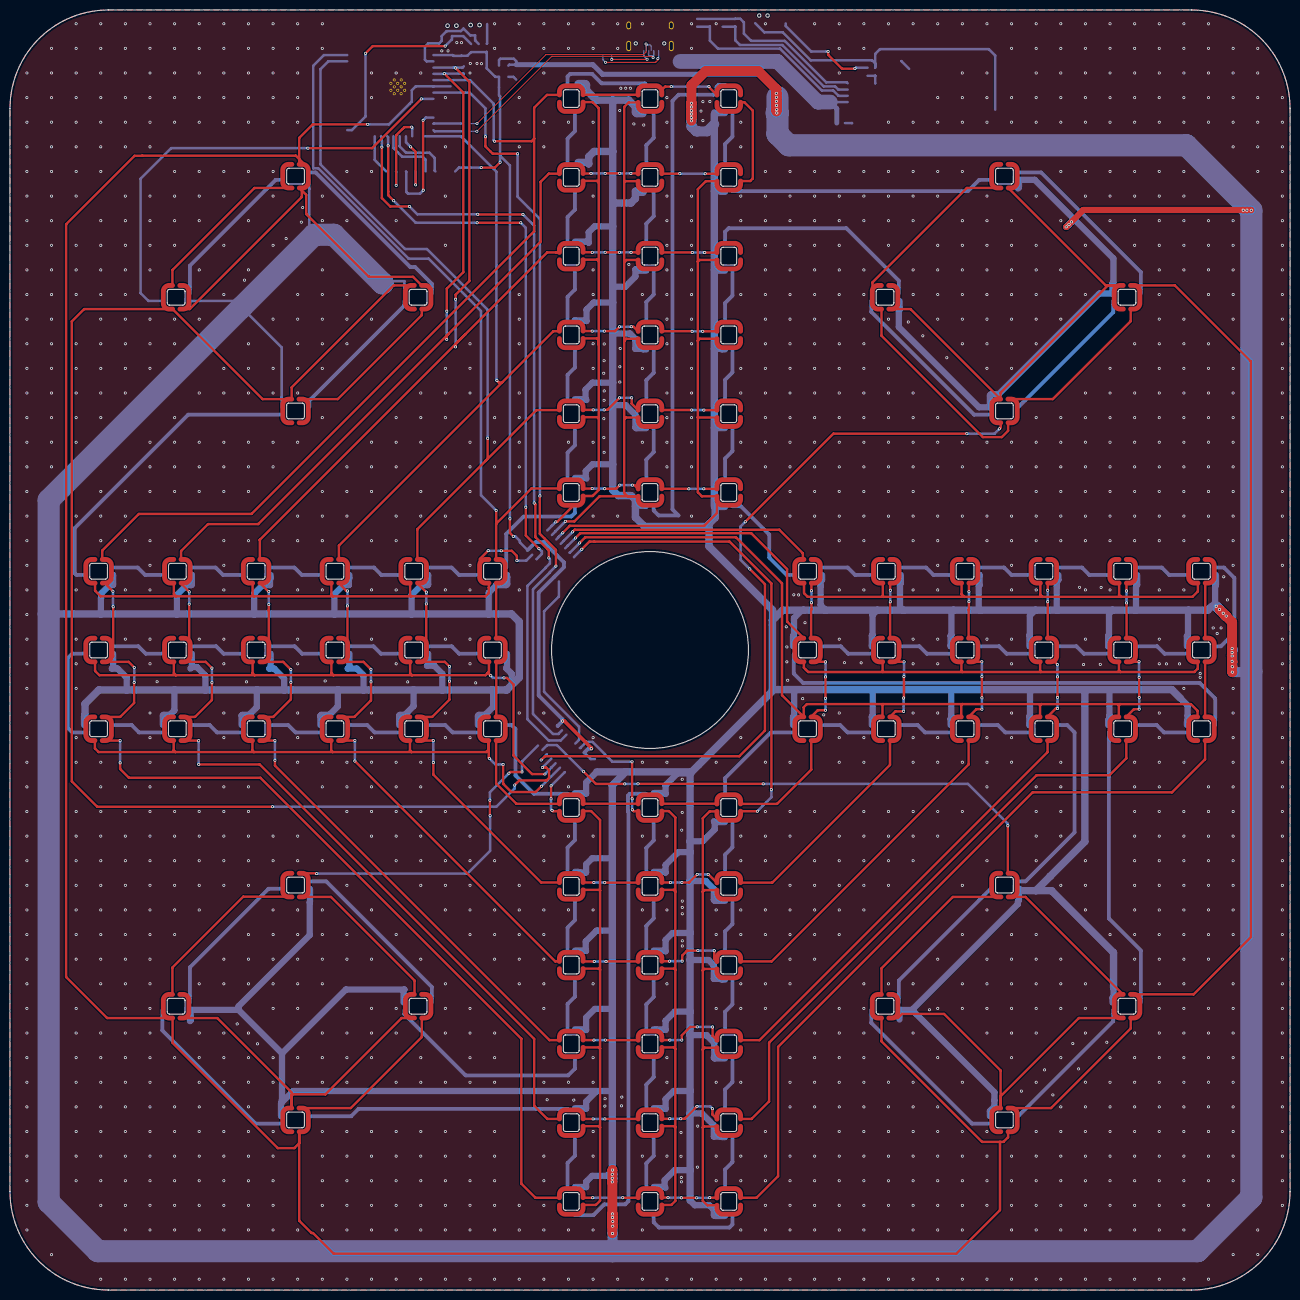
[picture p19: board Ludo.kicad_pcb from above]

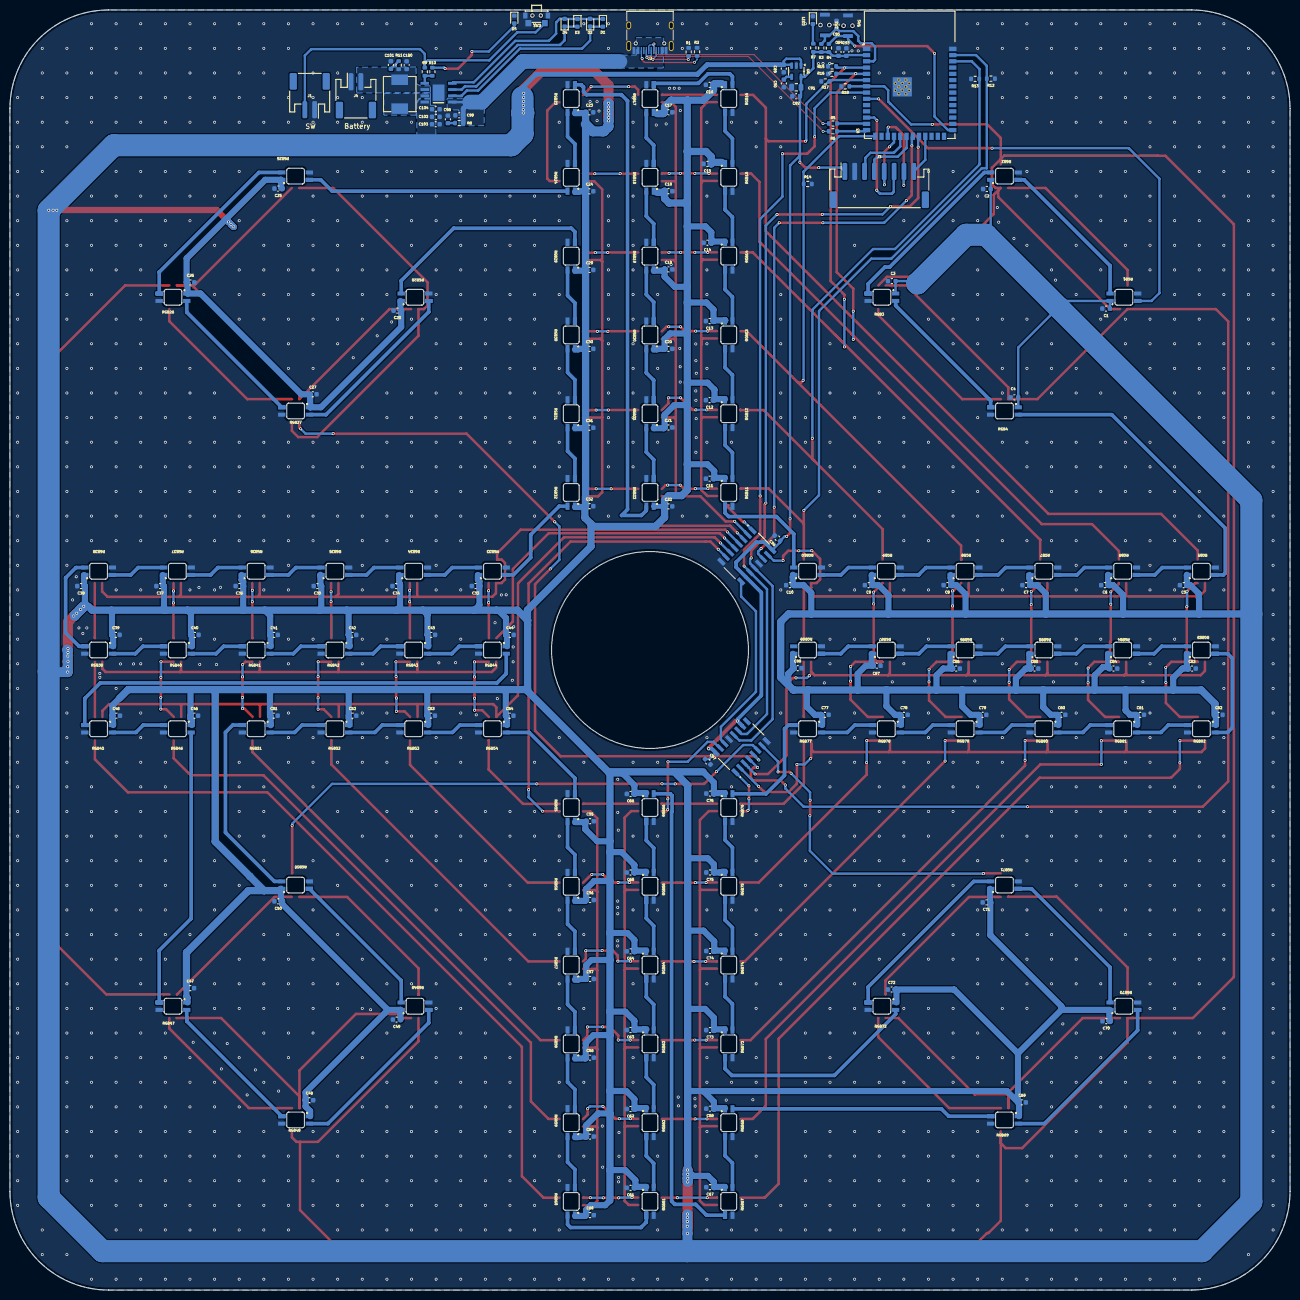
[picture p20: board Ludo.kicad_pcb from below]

Board: 2 copper layers, 260.0 x 260.0 mm, 229 parts (229 on the bottom side), 145 nets.

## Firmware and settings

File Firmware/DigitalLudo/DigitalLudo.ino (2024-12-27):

/*
 * Project Name: Digital Ludo Board
 * Project Brief: Firmware for Digital Ludo Board built around ESP-32S3
 * Author: Jobit Joseph @ https://github.com/jobitjoseph
 * IDE: Arduino IDE 2.3.4
 * Arduino Core: ESP32 Arduino Core V 3.1.0
 * Arduino Board Config: Board: ESP32-S3 Dev Module
 *                       USB CDC On Boot : Enable
 *                       Flash Size : 16MB(128mb)
 *                       Partition Scheme : Custom
 *                       PSRAM : OPI PSRAM
 * Dependencies : Adafruit NeoPixel Library V 1.12.2 @ https://github.com/teknynja/Adafruit_NeoPixel
 *                PNGDec Library V 1.0.3 @https://github.com/bitbank2/PNGdec
 *                TFT_eSPI Library V 2.5.43 @https://github.com/Bodmer/TFT_eSPI
 *                AnimatedGIF Library V 2.1.1 @ https://github.com/bitbank2/AnimatedGIF
 * Hardware : ESP32-S3-WROOM-1-N16R8
 *            Waveshare 1.28inch Round LCD Display Module, 65K RGB 240x240
 *            74HC595 Shiftregister
 *            SK6812MINI-E RGB LED
 *            IP5306 Power Managment IC
 * Copyright B) Jobit Joseph
 * Copyright B) Semicon Media Pvt Ltd
 * Copyright B) Circuitdigest.com
 *
 * This code is licensed under the following conditions:
 *
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
 * 2. Commercial Use:
 * For any commercial use of this software, you must obtain a separate license
 * from the original author. Contact the author for permissions or licensing
 * options before using this software for commercial purposes.
 *
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
 * Author: Jobit Joseph
 * Date: 25 December 2024
 *
 * For commercial use or licensing requests, please contact [jobitjoseph1@gmail.com].
 */

#include "esp_sleep.h"
/*PNG decoder library*/
#include <PNGdec.h>          // Include the PNG decoder library
PNG png;                     // PNG decoder instance
#define MAX_IMAGE_WIDTH 240  // Adjust for your images
int16_t xpos = 0;
int16_t ypos = 0;
/*PNG decoder library*/
#include <Adafruit_NeoPixel.h>  //Adafruit neopixel Library
Adafruit_NeoPixel strip(88, 16, NEO_GRB + NEO_KHZ800);
const unsigned long flashInterval = 300;  // Fixed flash interval (300ms)

#include <SPI.h>
#include <TFT_eSPI.h>  //.  TFT_eSPI Library
TFT_eSPI tft = TFT_eSPI();

#include <AnimatedGIF.h>  // AnimatedGIF Library
#include "NotoSansBold36.h"
#include "ImgData.h"
AnimatedGIF gif;
#define GIF_IMAGE0 Ludo_intro
#define GIF_IMAGE00 Confetti
#define GIF_IMAGE11 Congrats
#define GIF_IMAGE1 Dice_1
#define GIF_IMAGE2 Dice_2
#define GIF_IMAGE3 Dice_3
#define GIF_IMAGE4 Dice_4
#define GIF_IMAGE5 Dice_5
#define GIF_IMAGE6 Dice_6
#define AA_FONT_LARGE NotoSansBold36
const uint8_t *gifImages[] = { GIF_IMAGE1, GIF_IMAGE2, GIF_IMAGE3, GIF_IMAGE4, GIF_IMAGE5, GIF_IMAGE6 };

const size_t gifSizes[] = {
  sizeof(GIF_IMAGE1),
  sizeof(GIF_IMAGE2),
  sizeof(GIF_IMAGE3),
  sizeof(GIF_IMAGE4),
  sizeof(GIF_IMAGE5),
  sizeof(GIF_IMAGE6)
};

// Define shift register pins
#define DATA_PIN 13   // SER (Serial Data Input)
#define LATCH_PIN 14  // RCLK (Register Clock)
#define CLOCK_PIN 15  // SRCLK (Shift Register Clock)


// GPIO Management
const int adcPins[7] = { 1, 2, 3, 4, 5, 6, 7 };  // GPIO1 to GPIO7
const int SPIPins[6] = { 8, 9, 10, 11, 12, 21 };

//RGB LED Address Mapping
int ledMapping[16][6] = {
  { 9, 8, 7, 6, 5, 4 },
  { 10, 11, 12, 13, 14, 15 },
  { 21, 20, 19, 18, 17, 16 },
  { 31, 30, 29, 28, 23, 22 },
  { 32, 33, 34, 35, 36, 37 },
  { 43, 42, 41, 40, 39, 38 },
  { 53, 52, 51, 50, 45, 44 },
  { 54, 55, 56, 57, 58, 59 },
  { 65, 64, 63, 62, 61, 60 },
  { 75, 74, 73, 72, 67, 66 },
  { 76, 77, 78, 79, 80, 81 },
  { 87, 86, 85, 84, 83, 82 },
  { 0, 1, 2, 3, -1, -1 },
  { 24, 25, 26, 27, -1, -1 },
  { 46, 47, 48, 49, -1, -1 },
  { 68, 69, 70, 71, -1, -1 },
};


// Touch detection threshold (adjust based on calibration)
int TOUCH_THRESHOLD = 20;  // Example value; calibrate for your setup
// Debounce settings
#define DEBOUNCE_COUNT 3
unsigned long lastdbug = 0;
// Arrays to hold touch states and debounce counters
uint8_t touchState[16][7] = { 0 };
uint8_t debounceCounter[16][7] = { 0 };
uint8_t stableState[16][7] = { 0 };


//Global Variables for Game Logic
int currentPlayer = 0;
int mode = 0;
int TotalWins = 0;  //To store number of player with all 4 tokens in home
int rollsInTurn = 0;
int diceRoll;            // Count of rolls in the current turn
bool extraRoll = false;  // Track if player gets a bonus roll
int highestRoll = 0;
int startingPlayer = -1;
int PlayerSetupCount = 0;

String Player[] = { "Blue", "Yellow", "Green", "Red" };
int rolls[4] = { 0 };
int HighRoller[] = { 0, 0, 0, 0 };
int PlayerPlace[4] = { 0, 0, 0, 0 };   // Player position for Blue, Yellow, Green, Red
int tokensInHome[4] = { 0, 0, 0, 0 };  // Tokens in home for Blue, Yellow, Green, Red
int tokensInMove[4] = { 0, 0, 0, 0 };
int tokensInStart[4] = { 4, 4, 4, 4 };  // Tokens in start for Blue, Yellow, Green, Red
//int playerPositions[4][4] = {{5,5,3,4},{44,44,3,4},{32,32,3,4},{19,19,3,4}}; // Token positions for each player (relative to their path)
int playerPositions[4][4] = { { 1, 2, 3, 4 }, { 1, 2, 3, 4 }, { 1, 2, 3, 4 }, { 1, 2, 3, 4 } };  // Token positions for each player (relative to their path)
// Paths for each player
const int bluePath[] = { -1, 0, 1, 2, 3, 5, 6, 7, 8, 9, 10, 11, 12, 13, 14, 15, 16, 22, 23, 28, 29, 30, 31, 32, 33, 34, 35, 36, 37, 38, 44, 45, 50, 51, 52, 53, 54, 55, 56, 57, 58, 59, 60, 66, 67, 72, 73, 74, 75, 76, 77, 78, 79, 80, 81, 82, 83, 84, 85, 86, 87 };
const int yellowPath[] = { -1, 24, 25, 26, 27, 23, 28, 29, 30, 31, 32, 33, 34, 35, 36, 37, 38, 44, 45, 50, 51, 52, 53, 54, 55, 56, 57, 58, 59, 60, 66, 67, 72, 73, 74, 75, 76, 77, 78, 79, 80, 81, 82, 4, 5, 6, 7, 8, 9, 10, 11, 12, 13, 14, 15, 16, 17, 18, 19, 20, 21 };
const int greenPath[] = { -1, 46, 47, 48, 49, 45, 50, 51, 52, 53, 54, 55, 56, 57, 58, 59, 60, 66, 67, 72, 73, 74, 75, 76, 77, 78, 79, 80, 81, 82, 4, 5, 6, 7, 8, 9, 10, 11, 12, 13, 14, 15, 16, 22, 23, 28, 29, 30, 31, 32, 33, 34, 35, 36, 37, 38, 39, 40, 41, 42, 43 };
const int redPath[] = { -1, 68, 69, 70, 71, 67, 72, 73, 74, 75, 76, 77, 78, 79, 80, 81, 82, 4, 5, 6, 7, 8, 9, 10, 11, 12, 13, 14, 15, 16, 22, 23, 28, 29, 30, 31, 32, 33, 34, 35, 36, 37, 38, 44, 45, 50, 51, 52, 53, 54, 55, 56, 57, 58, 59, 60, 61, 62, 63, 64, 65 };
const int *playerPaths[] = { bluePath, yellowPath, greenPath, redPath };
const int pathLengths[] = { sizeof(bluePath) / sizeof(int), sizeof(yellowPath) / sizeof(int), sizeof(greenPath) / sizeof(int), sizeof(redPath) / sizeof(int) };

// Player colors
#define COLOR_BLUE strip.Color(0, 0, 255)
#define COLOR_YELLOW strip.Color(255, 255, 0)
#define COLOR_GREEN strip.Color(0, 255, 0)
#define COLOR_RED strip.Color(255, 0, 0)
const uint32_t playerColors[] = { COLOR_BLUE, COLOR_YELLOW, COLOR_GREEN, COLOR_RED };

// Safe squares
const int safeSquares[] = { 5, 13, 23, 35, 45, 57, 67, 79 };
#define SAFE_SQUARES_COUNT (sizeof(safeSquares) / sizeof(int))

struct LEDState {
  int playerColors[4];       // Colors of overlapping players
  int count;                 // Number of overlapping players
  unsigned long lastUpdate;  // Timestamp of the last update
  int currentIndex;          // Current color index for flashing
  bool state;                // ON/OFF state for flashing
};
LEDState ledStates[150];  // Array to track LED states (adjust size as needed)


// Global variable to track inactivity
unsigned long lastTouchTime = 0;                  // Tracks the last touch input time
const unsigned long INACTIVITY_TIMEOUT = 900000;  // 15 minutes in milliseconds

// Function to handle deep sleep
void goToSleep() {
  // Turn off all LEDs
  strip.clear();
  strip.show();

  // Turn off the display
  tft.writecommand(TFT_DISPOFF);  // Turn off display
  tft.writecommand(TFT_SLPIN);    // Enter sleep mode for display
  pinMode(21, OUTPUT);
  digitalWrite(21, LOW);  //turn of lcd backlight

  // Configure wake-up source (e.g., touch input, GPIO, timer, etc.)
  esp_sleep_enable_ext0_wakeup(GPIO_NUM_0, 0);  // Replace GPIO_NUM_33 with your desired GPIO
  //esp_sleep_enable_timer_wakeup(60000000);     // Optional: Wake after 1 minute if needed

  Serial.println("Going to sleep......!");

  // Enter deep sleep
  esp_deep_sleep_start();
}

// Function to handle inactivity
void handleInactivity() {
  unsigned long currentMillis = millis();

  // Check if 5 minutes of inactivity have passed
  if (currentMillis - lastTouchTime > INACTIVITY_TIMEOUT) {
    goToSleep();
  }
}

// Function to initialize shift register pins
void setupShiftRegisters() {
  pinMode(DATA_PIN, OUTPUT);
  pinMode(LATCH_PIN, OUTPUT);
  pinMode(CLOCK_PIN, OUTPUT);
  // Initialize shift registers to all zeros
  shiftOutData(0);
}

// Function to initialize ADC input pins
void setupADC() {
  for (int i = 0; i < 7; i++) {
    pinMode(adcPins[i], OUTPUT);
  }
}

// Function to scan the entire matrix
void scanMatrix() {
  for (int row = 0; row < 16; row++) {
    activateRow(row);
    delayMicroseconds(50);  // Small delay to allow signals to stabilize
    readColumns(row);
  }
}

// Function to activate a specific row using shift registers
void activateRow(int row) {
  uint16_t data = 1 << row;  // Create a bitmask to activate the current row
  shiftOutData(data);
}

// Function to shift out data to the shift registers
void shiftOutData(uint16_t data) {
  digitalWrite(LATCH_PIN, LOW);
  for (int i = 15; i >= 0; i--) {
    digitalWrite(CLOCK_PIN, LOW);
    digitalWrite(DATA_PIN, (data & (1 << i)) ? HIGH : LOW);
    digitalWrite(CLOCK_PIN, HIGH);
  }
  digitalWrite(LATCH_PIN, HIGH);
}

// Function to read the columns (ADC inputs) for the active row
void readColumns(int row) {
  for (int col = 0; col < 7; col++) {
    pinMode(adcPins[col], INPUT);
    int adcValue = analogRead(adcPins[col]);
    pinMode(adcPins[col], OUTPUT);
    digitalWrite(adcPins[col], 0);
    touchState[row][col] = (adcValue > TOUCH_THRESHOLD) ? 1 : 0;
  }
}

// Function to handle debounce logic
void debounceKeys() {
  for (int row = 0; row < 16; row++) {
    for (int col = 0; col < 7; col++) {
      if (touchState[row][col] == stableState[row][col]) {
        debounceCounter[row][col] = 0;  // Reset counter if state is stable
      } else {
        debounceCounter[row][col]++;
        if (debounceCounter[row][col] >= DEBOUNCE_COUNT) {
          stableState[row][col] = touchState[row][col];
          debounceCounter[row][col] = 0;
          handleKeyEvent(row, col, stableState[row][col]);
        }
      }
    }
  }
}

// Function to handle key events (presses and releases)
void handleKeyEvent(int row, int col, uint8_t state) {
  if (state == 1) {
    return;
  } else {
    // Key released
    lastTouchTime = millis();  // Reset the inactivity timer
    if (row < 12) {
      Serial.print("Touch at  : ");
      Serial.println(ledMapping[row][col]);
      handleTokenMove(ledMapping[row][col]);
    } else {
      Serial.print("Player  : ");
      Serial.println(row - 12);
      handleTokenMove(100 + (row - 12));
    }
  }
}

// Optional: Function to calibrate touch threshold
void calibrateTouchThreshold() {
  int maxValue = 0;
  for (int col = 0; col < 7; col++) {
    int adcValue = analogRead(adcPins[col]);
    if (adcValue > maxValue) {
      maxValue = adcValue;
    }
  }
  // Set TOUCH_THRESHOLD slightly above the maximum observed value
  TOUCH_THRESHOLD = maxValue + 100;  // Adjust the offset as needed
}

void pngDraw(PNGDRAW *pDraw) {
  uint16_t lineBuffer[MAX_IMAGE_WIDTH];
  png.getLineAsRGB565(pDraw, lineBuffer, PNG_RGB565_BIG_ENDIAN, 0xffffffff);
  tft.pushImage(xpos, ypos + pDraw->y, pDraw->iWidth, 1, lineBuffer);
}

void DisplayPNG(const uint8_t *pngArray, size_t arraySize) {
  int16_t rc = png.openFLASH((uint8_t *)pngArray, arraySize, pngDraw);
  if (rc == PNG_SUCCESS) {
    Serial.println("Successfully opened PNG file");
    Serial.printf("Image specs: (%d x %d), %d bpp, pixel type: %d\n",
                  png.getWidth(), png.getHeight(), png.getBpp(), png.getPixelType());

    tft.startWrite();
    uint32_t dt = millis();
    rc = png.decode(NULL, 0);
    Serial.print(millis() - dt);
    Serial.println("ms");
    tft.endWrite();
    // png.close(); // Not needed for memory-to-memory decode
  } else {
    Serial.println("Failed to open PNG file");
  }
}

void playGIF(const uint8_t *gifImage, size_t gifSize) {
  //size_t gifSize = sizeof(gifImage); // Automatically calculate size
  if (gif.open((uint8_t *)gifImage, gifSize, GIFDraw)) {
    Serial.printf("Successfully opened GIF; Canvas size = %d x %d\n", gif.getCanvasWidth(), gif.getCanvasHeight());
    tft.startWrite();
    while (gif.playFrame(true, NULL)) {
      yield();
    }
    gif.close();
    tft.endWrite();
  } else {
    Serial.println("Failed to open GIF!");
  }
}
void drawLudoHomeArea(int tokensBlue, int tokensYellow, int tokensGreen, int tokensRed, int centerColorFlag) {
  // Colors for tokens and placeholders
  uint16_t blueColor = 0x0294;
  uint16_t yellowColor = 0xd5a0;
  uint16_t greenColor = 0x4420;
  uint16_t redColor = 0xb021;
  uint16_t centerCircleColor;

  // Set center circle color based on the flag
  switch (centerColorFlag) {
    case 0:
      centerCircleColor = blueColor;
      break;  // Light Blue
    case 1:
      centerCircleColor = yellowColor;
      break;
    case 2:
      centerCircleColor = greenColor;
      break;
    case 3:
      centerCircleColor = redColor;
      break;
    default:
      centerCircleColor = blueColor;
      break;  // Default to Light Blue
  }

  // Screen dimensions (assuming circular display of 240x240 pixels)
  int screenWidth = 240;
  int screenHeight = 240;
  int centerX = screenWidth / 2;
  int centerY = screenHeight / 2;
  int radius = screenWidth / 2;

  // Clear screen
  tft.fillScreen(TFT_BLACK);

  // Draw quadrant backgrounds
  tft.fillTriangle(centerX, centerY, 0, 0, screenWidth, 0, yellowColor);                      // Top-right (Yellow)
  tft.fillTriangle(centerX, centerY, screenWidth, 0, screenWidth, screenHeight, greenColor);  // Bottom-right (Green)
  tft.fillTriangle(centerX, centerY, screenWidth, screenHeight, 0, screenHeight, redColor);   // Bottom-left (Red)
  tft.fillTriangle(centerX, centerY, 0, screenHeight, 0, 0, blueColor);                       // Top-left (Blue)

  // Draw center circle
  int centerRadius = 49;                                          // Circle radius is 50 pixels diameter
  tft.fillCircle(centerX, centerY, centerRadius + 2, TFT_BLACK);  // Outer border
  tft.fillCircle(centerX, centerY, centerRadius, centerCircleColor);

  // Function to draw tokens and placeholders at left, right, top, and bottom centers
  auto drawTokens = [&](int cx, int cy, uint16_t color, int tokenCount) {
    int tokenRadius = 10;
    int spacing = 20;   // Spacing between tokens
    int maxTokens = 4;  // Max tokens per quadrant

    // Calculate positions for tokens (left, right, top, bottom centers of the quadrant)
    int positions[4][2] = {
      { cx, cy + spacing },  // Left
      { cx, cy - spacing },  // Right
      { cx - spacing, cy },  // Top
      { cx + spacing, cy }   // Bottom
    };

    for (int i = 0; i < maxTokens; i++) {
      int x = positions[i][0];
      int y = positions[i][1];

      if (i < tokenCount) {
        tft.fillCircle(x, y, tokenRadius + 2, TFT_BLACK);  // Outer outline
        tft.fillCircle(x, y, tokenRadius, color);          // Filled token
        tft.fillCircle(x, y, tokenRadius - 4, TFT_BLACK);  // Inner outline
      } else {
        tft.fillCircle(x, y, tokenRadius + 2, TFT_BLACK);  // Outer outline
        tft.fillCircle(x, y, tokenRadius, TFT_WHITE);      // Placeholder
      }
    }
  };

  // Draw tokens for each quadrant
  drawTokens(34, 120, blueColor, tokensBlue);      // Top-left (Blue)
  drawTokens(120, 34, yellowColor, tokensYellow);  // Top-right (Yellow)
  drawTokens(206, 120, greenColor, tokensGreen);   // Bottom-right (Green)
  drawTokens(120, 206, redColor, tokensRed);       // Bottom-left (Red)
}

void displayHighRollers(int left, int top, int right, int bottom, int offset) {
  if (left > 0) {
    tft.drawNumber(left, offset, 120);
  }
  if (top > 0) {
    tft.drawNumber(top, 120, offset);
  }
  if (right > 0) {
    tft.drawNumber(right, 240 - offset, 120);
  }
  if (bottom > 0) {
    tft.drawNumber(bottom, 120, 240 - offset);
  }
}

// Update LEDs
void updateLEDs() {
  const int numPlayers = 4;               // Total players
  const int numTokens = 4;                // Tokens per player
  const int numLEDs = strip.numPixels();  // Total LEDs

  // Reset the LED states
  for (int i = 0; i < numLEDs; i++) {
    ledStates[i].count = 0;
  }

  // Populate LED states
  for (int player = 0; player < numPlayers; player++) {
    for (int token = 0; token < numTokens; token++) {
      int pos = playerPositions[player][token];
      if (pos > 0 && pos < pathLengths[player]) {
        int ledIndex = playerPaths[player][pos];
        if (ledStates[ledIndex].count < numPlayers) {
          ledStates[ledIndex].playerColors[ledStates[ledIndex].count] = playerColors[player];
          ledStates[ledIndex].count++;
        }
      }
    }
  }

  // Update LEDs based on their states
  unsigned long currentMillis = millis();
  for (int i = 0; i < numLEDs; i++) {
    if (ledStates[i].count == 0) {
      // No tokens on this LED, turn it off
      strip.setPixelColor(i, 0);
    } else if (ledStates[i].count == 1) {
      // Single token, set to static color
      strip.setPixelColor(i, ledStates[i].playerColors[0]);
    } else {
      // Multiple tokens, handle flashing
      if (currentMillis - ledStates[i].lastUpdate >= flashInterval) {
        ledStates[i].lastUpdate = currentMillis;
        if (ledStates[i].state) {
          // Turn the LED off
          strip.setPixelColor(i, 0);
        } else {
          // Set the LED to the current color
          strip.setPixelColor(i, ledStates[i].playerColors[ledStates[i].currentIndex]);
          // Move to the next color
          ledStates[i].currentIndex = (ledStates[i].currentIndex + 1) % ledStates[i].count;
        }
        ledStates[i].state = !ledStates[i].state;
      }
    }
  }

  strip.show();
}

void setupPlayers() {
  DisplayPNG((uint8_t *)StartMessage, sizeof(StartMessage));
  Serial.println("Any Player touch start area!");
  while (mode == 5) {
    scanMatrix();
    debounceKeys();
    updateLEDs();
    handleInactivity();
    if (millis() - lastdbug > 1000) {
      Serial.print("Mode: ");
      Serial.print(mode);
      Serial.print(" Player with High Roll: ");
      Serial.println(startingPlayer + 1);
      lastdbug = millis();
    }
  }
  currentPlayer = startingPlayer;
  DisplayPNG((uint8_t *)FirstPlayer, sizeof(FirstPlayer));
  tft.drawString(Player[currentPlayer], 120, 91);
  delay(2000);
}

// Manage player turns
void nextPlayer() {
  if (rollsInTurn > 0) {
    rollsInTurn = 0;
  }
  do {
    currentPlayer = (currentPlayer + 1) % 4;   // Move to the next player
  } while (tokensInHome[currentPlayer] == 4);  // Continue until a valid player is found
  mode = 0;
}

// Take token out of start area
void TakeTokenOut() {
  for (int i = 0; i < 4; i++) {
    if (playerPositions[currentPlayer][i] < 5) {
      playerPositions[currentPlayer][i] = 5;
      detectCollision(currentPlayer, playerPositions[currentPlayer][i]);
      tokensInStart[currentPlayer]--;
      tokensInMove[currentPlayer]++;
      return;
    }
  }
}

//Detect collision
void detectCollision(int currentPlayer, int movedTokenIndex) {
  // Get the new position of the moved token
  int newPosition = playerPaths[currentPlayer][movedTokenIndex];

  // Check if the new position is a safe square
  for (int i = 0; i < SAFE_SQUARES_COUNT; i++) {
    if (newPosition == safeSquares[i]) {
      // Safe square; do nothing
      return;
    }
  }

  // Check for collisions with other players
  for (int otherPlayer = 0; otherPlayer < 4; otherPlayer++) {
    if (otherPlayer == currentPlayer) {
      continue;  // Skip the current player
    }

    for (int otherToken = 0; otherToken < 4; otherToken++) {
      if (playerPaths[otherPlayer][otherToken] == newPosition) {
        // Collision detected; move the other player's token to a vacant start point
        for (int i = 1; i < 5; i++) {
          if (playerPositions[otherPlayer][0] != i && playerPositions[otherPlayer][1] != i && playerPositions[otherPlayer][2] != i && playerPositions[otherPlayer][3] != i) {
            playerPositions[otherPlayer][otherToken] = i;  // Move to start
            tokensInStart[otherPlayer]++;
            tokensInMove[otherPlayer]--;
            Serial.print("Collision! Token from player ");
            Serial.print(otherPlayer + 1);
            Serial.print(" moved back to start position.");
            Serial.println();
            break;
          }
          return;
        }
      }
    }
  }
}
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
void loop() {
  int count = 0;
  int winner = -1;  // Variable to track the winning player

  for (int i = 0; i < 4; i++) {
    if (tokensInHome[i] == 4) {
      count++;
      winner = i;  // Set the winner
    }
  }
  // If any player has all tokens in home, play the Congrats GIF
  if (count > 0) {

    while (true) {                // Loop indefinitely to show the Congrats GIF
      tft.fillScreen(TFT_BLACK);  // Clear the screen
      playGIF(Confetti, sizeof(Confetti));
      playGIF(Congrats, sizeof(Congrats));
      tft.drawString("WINNER", 120, 40);
      tft.drawString(Player[winner], 120, 200);
      delay(2000);
    }
  }

  scanMatrix();
  debounceKeys();
  updateLEDs();
  handleInactivity();
  delay(10);  // Adjust the delay as needed for your application
}

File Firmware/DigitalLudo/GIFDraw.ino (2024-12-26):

/*
 * Project Name: Digital Ludo Board
 * Project Brief: Firmware for Digital Ludo Board built around ESP-32S3
 * Author: Jobit Joseph @ https://github.com/jobitjoseph
 * IDE: Arduino IDE 2.3.4
 * Arduino Core: ESP32 Arduino Core V 3.1.0
 * Dependencies : Adafruit NeoPixel Library V 1.12.2 @ https://github.com/adafruit/Adafruit_NeoPixel
 *                PNGDec Library V 1.0.3 @https://github.com/bitbank2/PNGdec
 *                TFT_eSPI Library V 2.5.43 @https://github.com/Bodmer/TFT_eSPI
 *                AnimatedGIF Library V 2.1.1 @ https://github.com/bitbank2/AnimatedGIF
 * Hardware : ESP32-S3-WROOM-1-N16R8
 *            Waveshare 1.28inch Round LCD Display Module, 65K RGB 240x240
 *            74HC595 Shiftregister
 *            SK6812MINI-E RGB LED
 *            IP5306 Power Managment IC
 * Copyright © Jobit Joseph
 * Copyright © Semicon Media Pvt Ltd
 * Copyright © Circuitdigest.com
 * 
 * This code is licensed under the following conditions:
 *
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
 * 2. Commercial Use:
 * For any commercial use of this software, you must obtain a separate license
 * from the original author. Contact the author for permissions or licensing
 * options before using this software for commercial purposes.
 *
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
 * Author: Jobit Joseph
 * Date: 25 December 2024
 *
 * For commercial use or licensing requests, please contact [jobitjoseph1@gmail.com].
 */


#define DISPLAY_WIDTH  tft.width()
#define DISPLAY_HEIGHT tft.height()
#define BUFFER_SIZE 256            // Optimum is >= GIF width or integral division of width

#ifdef USE_DMA
uint16_t usTemp[2][BUFFER_SIZE]; // Global to support DMA use
#else
uint16_t usTemp[1][BUFFER_SIZE];    // Global to support DMA use
#endif
bool     dmaBuf = 0;

// Draw a line of image directly on the LCD
void GIFDraw(GIFDRAW *pDraw)
{
	uint8_t *s;
	uint16_t *d, *usPalette;
	int x, y, iWidth, iCount;

	// Displ;ay bounds chech and cropping
	iWidth = pDraw->iWidth;
	if (iWidth + pDraw->iX > DISPLAY_WIDTH)
		iWidth = DISPLAY_WIDTH - pDraw->iX;
	usPalette = pDraw->pPalette;
	y = pDraw->iY + pDraw->y; // current line
	if (y >= DISPLAY_HEIGHT || pDraw->iX >= DISPLAY_WIDTH || iWidth < 1)
		return;

	// Old image disposal
	s = pDraw->pPixels;
	if (pDraw->ucDisposalMethod == 2) // restore to background color
	{
		for (x = 0; x < iWidth; x++)
		{
			if (s[x] == pDraw->ucTransparent)
				s[x] = pDraw->ucBackground;
		}
		pDraw->ucHasTransparency = 0;
	}

	// Apply the new pixels to the main image
	if (pDraw->ucHasTransparency) // if transparency used
	{
		uint8_t *pEnd, c, ucTransparent = pDraw->ucTransparent;
		pEnd = s + iWidth;
		x = 0;
		iCount = 0; // count non-transparent pixels
		while (x < iWidth)
		{
			c = ucTransparent - 1;
			d = &usTemp[0][0];
			while (c != ucTransparent && s < pEnd && iCount < BUFFER_SIZE )
			{
				c = *s++;
				if (c == ucTransparent) // done, stop
				{
					s--; // back up to treat it like transparent
				}
				else // opaque
				{
					*d++ = usPalette[c];
					iCount++;
				}
			} // while looking for opaque pixels
			if (iCount) // any opaque pixels?
			{
				// DMA would degrtade performance here due to short line segments
				tft.setAddrWindow(pDraw->iX + x, y, iCount, 1);
				tft.pushPixels(usTemp, iCount);
				x += iCount;
				iCount = 0;
			}
			// no, look for a run of transparent pixels
			c = ucTransparent;
			while (c == ucTransparent && s < pEnd)
			{
				c = *s++;
				if (c == ucTransparent)
					x++;
				else
					s--;
			}
		}
	}
	else
	{
		s = pDraw->pPixels;

		// Unroll the first pass to boost DMA performance
		// Translate the 8-bit pixels through the RGB565 palette (already byte reversed)
		if (iWidth <= BUFFER_SIZE)
			for (iCount = 0; iCount < iWidth; iCount++) usTemp[dmaBuf][iCount] = usPalette[*s++];
		else
			for (iCount = 0; iCount < BUFFER_SIZE; iCount++) usTemp[dmaBuf][iCount] = usPalette[*s++];

#ifdef USE_DMA // 71.6 fps (ST7796 84.5 fps)
		tft.dmaWait();
		tft.setAddrWindow(pDraw->iX, y, iWidth, 1);
		tft.pushPixelsDMA(&usTemp[dmaBuf][0], iCount);
		dmaBuf = !dmaBuf;
#else // 57.0 fps
		tft.setAddrWindow(pDraw->iX, y, iWidth, 1);
		tft.pushPixels(&usTemp[0][0], iCount);
#endif

		iWidth -= iCount;
		// Loop if pixel buffer smaller than width
		while (iWidth > 0)
		{
			// Translate the 8-bit pixels through the RGB565 palette (already byte reversed)
			if (iWidth <= BUFFER_SIZE)
				for (iCount = 0; iCount < iWidth; iCount++) usTemp[dmaBuf][iCount] = usPalette[*s++];
			else
				for (iCount = 0; iCount < BUFFER_SIZE; iCount++) usTemp[dmaBuf][iCount] = usPalette[*s++];

#ifdef USE_DMA
			tft.dmaWait();
			tft.pushPixelsDMA(&usTemp[dmaBuf][0], iCount);
			dmaBuf = !dmaBuf;
#else
			tft.pushPixels(&usTemp[0][0], iCount);
#endif
			iWidth -= iCount;
		}
	}
} /* GIFDraw() */
